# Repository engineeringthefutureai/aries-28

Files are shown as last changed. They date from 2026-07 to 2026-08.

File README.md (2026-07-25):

# Aries 28

**A tower-format mini private data center — a Raspberry Pi cluster that is a self-hosted private cloud, a k3s learning platform, and a documented hardware build, in one buildable box.**

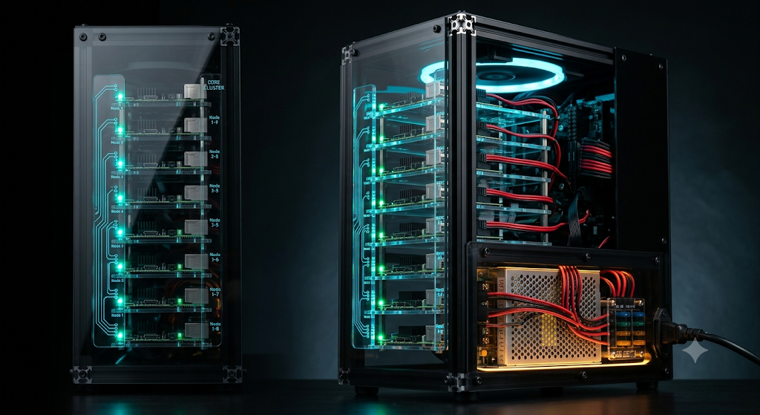
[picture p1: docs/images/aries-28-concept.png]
Aries 28 — concept render


> *Concept render (AI-generated) shown as the design target. To be replaced with a staged photograph of the real build.*

Aries 28 is an open hardware + software project: a **mini private data center** in a desktop tower — a cluster of Raspberry Pi boards running a real Kubernetes (k3s) cluster with distributed storage, housed in a laser-cut / 3D-printed / CNC enclosure. It has, in miniature, what a real data center has: redundant compute, a fused power-distribution system, managed cooling and airflow, structured network cabling, and a facilities layer (gateway, monitoring, orderly power sequencing). It is designed to be **replicated, understood, and modified** — every mechanical part, wiring decision, and cluster-setup step is documented, and the fabrication files are first-class artifacts alongside the code. An optional lighting layer is included for those who want it, but the enclosure and its illumination are presentation, not requirements.

It is deliberately *not* a performance machine. It is a machine for **learning** — Kubernetes control-plane redundancy, distributed storage, networking, power distribution, and physical fabrication — and a documented, hand-built piece of hardware. It provides node-level fault tolerance within the cluster; it is a single tower with acknowledged single points of failure (see the design doc), not a highly-available production system.

> **Status:** Active build. Documentation and design files are ahead of the physical build in places — treat this as a living project, not a finished kit.

---

## What it is

- **A mini data center:** redundant compute, fused power distribution, managed cooling, and structured cabling — the concerns of a real facility, at hobby scale, which is much of what makes it educational.
- **A cluster:** one or more single-board computers running k3s (lightweight Kubernetes) — starting from a single working node and scaling out with no fixed limit as boards are added. Added nodes become workers that expand the cluster's compute capacity; control-plane redundancy (HA with embedded etcd) is available along the way, but the cluster's growth is about overall capacity, not a fixed topology.
- **A private cloud:** distributed block storage and self-hosted apps, with an offline-capable design (self-hosted container registry, no external dependencies after setup).
- **An enclosure (optional aesthetic):** a black anodized 2020 aluminum-extrusion frame with acrylic panels, an exposed and serviceable power bay, and an optional lighting layer — including a status-lighting system that can reflect live cluster state. The styling is one implementation's choice, not a requirement.
- **A curriculum:** the build teaches control-plane quorum, distributed storage, routing/VLANs, infrastructure-as-code, power/fusing, and mechanical design — each embedded in a working part of the machine.

## What makes it different

Most Pi-cluster projects publish either the software (k3s scripts) *or* a case STL. Aries 28 aims to publish the **complete package**: mechanical design (STL / SVG / CAD), power and electrical design, cluster setup runbooks, and the reasoning behind each decision — so someone can replicate the whole thing or fork any layer of it.

The enclosure treats things other builds hide as **features**: the power supply and its wiring are on display behind smoked acrylic, dressed like the machine's power core; the boards ride on carriers that show through the panels; and the lighting does double duty as ambient mood and live status readout.

---

## Philosophy — earn the right to scale

Aries 28 is built on one principle: **earn the right to scale.** Complexity is added only once the simpler version works and its limits are understood — never preemptively.

**Start with one node.** The cluster begins as a single board on the workbench and is a *complete, working cluster at that stage* — it schedules workloads and serves traffic with one node. There is no "not yet functional" phase waiting on the rest of the hardware. From there it grows: a second node, then a high-availability control plane, then storage replication, then the physical enclosure — each step added because the previous one was proven and its constraints were felt firsthand. You don't build a distributed system to learn distribution; you build the smallest working thing and let its failures teach you what the next piece is for.

**The physical form earns its complexity the same way.** Boards run on the bench before they get a frame. The frame is proven square before panels go on. Lighting starts as a single power feed before it becomes a status system. Nothing is fabricated in final form until the design behind it has been tested — cardboard and cheap prints before acrylic and PETG.

**Neatness is engineering, not decoration.** A wire mess teaches nothing and hides its own faults; neatly organized, labeled, serviceable cabling is the foundation of a system you can actually grow and maintain. The same is true of the code and the documentation. The effort spent making the build *legible* — dressed cables, standardized interfaces, documented decisions — is not vanity; it is what makes the next change possible without a rebuild. A project you can't service is a project you can't scale.

**Aesthetics, practicality, and education reinforce each other rather than competing.** The tower is intended to be presentable, useful as a private cloud, and instructive to build. The exposed, dressed power bay is presentable because it is well-organized; the standardized carriers look deliberate because they make the machine serviceable; the optional status lighting is decorative and also conveys real cluster state. Well-organized engineering, shown honestly, is the source of the appearance.

The result is a machine that is never "half-built" — it works at every stage, looks deliberate at every stage, and teaches something at every stage. It just gets bigger, and better-dressed, as it earns it.

---

## Repository layout

```
aries-28/
├── docs/                    # design documents & runbooks
│   ├── architecture.md          # START HERE — the containment hierarchy & design spine
│   ├── design-doc.md            # master design: physical, power, BOM, build phases, SPOFs
│   ├── network-design.md        # topology, gateway, VLANs, switching, load balancing, I/O
│   ├── dns-and-exposure.md      # naming, DNS, ingress, service exposure, TLS
│   ├── rack-design.md           # rack & board-mounting mechanism
│   ├── lighting-design.md       # optional two-tier lighting system
│   ├── node-setup.md            # k3s + partitioned-storage node runbook
│   ├── images/                  # renders and (later) build-log photos
│   └── diagrams/                # architecture diagram (Graphviz source + render)
├── hardware/                # fabrication files, grouped BY PART (not by format)
│   ├── README.md                # parts index + fabrication legend (methods/materials)
│   └── <part>/                  # each part: its own README + all format options
├── kubernetes/              # cluster manifests (generic example included)
├── ansible/                 # node provisioning (infrastructure-as-code) — placeholder
├── LICENSE                  # dual: MIT (code) + CC-BY-SA 4.0 (hardware/docs)
└── .gitignore
```

**Start with [`docs/architecture.md`](docs/architecture.md)** — it describes the containment hierarchy (system → deck → rack → bay → carrier) and the stable-interface principle that the rest of the design refers back to.

**Hardware is organized by part, not by file format.** A single part (a board carrier, say) may have a `.svg` (sheet-cut), an `.stl` (3D print), and a source file side by side — these are *fabrication options*, not competing versions. Each part folder has a README explaining its purpose, the available routes, and any open decisions. See [`hardware/README.md`](hardware/README.md) for the parts index and the fabrication legend.

---

## Hardware overview

**Frame:** black anodized 2020 aluminum extrusion, compact mid-tower proportions. Corner hardware is bought (metal, for squareness); brackets, mounts, and carriers are fabricated.

**Fabrication is described by requirement, not by tool.** This project was built with a specific (limited) set of tools, but the repo documents what each part *needs* — material, dimensions, tolerances, hole positions — so you can make it with whatever you have: a CO2 or diode laser, a CNC router, or a hand saw and a drill following the drawing. The provided files (SVG/STL/STEP) are references; the **requirements** are the spec. Each part's README states its material and constraints and lists the methods that satisfy them.

Broad categories:
- **3D-printed parts (PETG)** — carriers, mounts, cable management, bezels, spacers. Small enough to print; PETG preferred over PLA for heat tolerance (near the PSU) and toughness (flexing latches) — each part README explains where the choice matters.
- **Sheet parts (acrylic)** — panels and optionally carriers. Flat stock cut to outer dimensions with holes/cutouts at specified coordinates. Achievable by CO2 laser, CNC router, or careful hand-cutting (table/circular saw) plus a drill press — the drawing gives the dimensions; the method is yours. Large panels **cannot** be 3D-printed (size), so they are always sheet stock.
- **Bought parts** — extrusion, corner brackets, rods, PSU, switch, fans: precision/strength items where off-the-shelf beats fabrication.

Some parts have **multiple valid routes** — e.g. a carrier can be 3D-printed in PETG *or* cut from acrylic (any color) on a laser/CNC with separate spacers. Clear or translucent acrylic gives more light transmission and edge-lit highlights; opaque/black gives contrast and hides what's behind it — the choice is aesthetic and depends on tool access and available materials. These are options, not a ranking; pick per your tools, materials, and preference.

**Boards — a deliberately heterogeneous fleet.** Different single-board-computer (SBC) generations and models play different roles, and their physical differences shape the wiring and mechanical design. This build uses Raspberry Pi boards, but the design is **not Pi-specific** — the standardized carrier/rack interface is meant to accommodate other SBCs too (Orange Pi and similar, or future SoC / compute modules), and even boards with different footprints. Larger boards (e.g. an Arduino Uno Q or an oversized SBC) may require a carrier variant or a bay-pitch adjustment, but the rack architecture is designed to absorb that rather than be rebuilt for it.

The Raspberry Pi fleet used here:

| Board | Role in cluster | Notable traits that affect the build |
|---|---|---|
| **Raspberry Pi 5** | control-plane / storage nodes | Has a built-in power button header (J2) — but its location on the board makes wiring a front-panel service button awkward; placement is an open design question. Fastest board; NVMe via PCIe HAT for storage. Ethernet port position differs from the Pi 4 (see cabling note below). |
| **Raspberry Pi 4** | gateway / worker nodes | **No built-in power-button header** — graceful shutdown for servicing needs an alternative (a GPIO-driven soft-power via `gpio-shutdown` overlay, or a wired button to the right pins). Ethernet port is on the **opposite side** vs. the Pi 5 (see cabling note below). |
| **Raspberry Pi 3A+** | LED / display driver ("face" node), outside the cluster | **No built-in Ethernet** — a USB-to-Ethernet adapter is used to keep it off Wi-Fi (the internal network is wired-only by design). Small footprint; drives the status LEDs and dashboard. |

**Board interchangeability & cabling.** Interchangeability is a **crucial design feature** — it's what makes future upgrades and expansion possible without rebuilding the machine. The carrier interface is standardized, and the carriers are shaped to **accommodate slightly different physical board shapes**, so a Pi 4, a Pi 5, or a different SBC entirely can occupy the same bay. Any node can be swapped for a newer or different board as generations improve, and empty bays can be populated later — the rack doesn't change. What differs between board types is mainly the **Ethernet jack position**, so the cabling is designed to absorb that: each node's Ethernet cable has **individually adjustable slack**, with the excess parked as a hidden service loop in the cable-management zone. Swapping one board type for another (jack a few cm over) is handled by adjusting that one cable's slack — no re-running cable, no harness rebuild, and other nodes' cabling is undisturbed.

**Cable management as a design element:** Ethernet runs are organized into neat parallel bundles using 3D-printed cable-holder braces. These do double duty — they hold the parallel runs so the wiring reads as deliberate (and photographs well through the panels), *and* they park each cable's adjustable service loop, so individual cables can be lengthened/shortened without touching the rest. Serviceability and aesthetics in one part.

**Power:** a single enclosed switching supply feeds a fused distribution bus; the power bay is vented and displayed as a feature. Mains safety (grounding, GFCI) is addressed in the design doc.

**Lighting:** two independent tiers — a non-addressable single-color ambient glow (no controller, powered straight from the fuse block) and a later addressable status system (reflects cluster state). See [`docs/lighting-design.md`](docs/lighting-design.md).

---

## Software overview

- **k3s** (lightweight Kubernetes) — starts as a single working node (a complete cluster on its own) and scales out with no fixed limit as nodes are added, expanding compute capacity. Control-plane redundancy (HA with embedded etcd) is available as the cluster grows.
- **Distributed storage** across nodes so a node loss doesn't lose data.
- **Offline-capable:** self-hosted container registry so the cluster can be rebuilt without internet access after initial setup.
- **Infrastructure-as-code:** node provisioning and cluster config are captured (Ansible + manifests), so nodes are reproducible rather than hand-configured.

Node bring-up — including partitioned NVMe (separate etcd and data), the Raspberry-Pi-specific kernel tweaks, and the k3s install — is documented step-by-step in [`docs/node-setup.md`](docs/node-setup.md).

---

## Lessons embedded in the build

Each is a working part of the machine, not a tutorial:

1. Kubernetes control-plane redundancy — etcd quorum, why 3 nodes (node-level fault tolerance, not system-wide HA)
2. Distributed storage and node-loss behavior
3. Routing / DHCP / DNS / VLANs (the gateway)
4. Infrastructure-as-code + GitOps
5. Power distribution, fusing, voltage-drop calibration
6. Node lifecycle: provision, drain, replace, recover
7. Scheduling on heterogeneous nodes (mixed RAM/roles)
8. Backup discipline
9. Power sequencing / orderly shutdown

---

## Status & roadmap

This is an in-progress build. Broad phases:

1. Bench cluster (prove software on loose boards)
2. Frame & power (fabricate, wire, calibrate)
3. Full integration (rack, panels, networking, control-plane quorum)
4. Cloud layer (storage, apps, registry)
5. Lighting & status system
6. Soft-power circuit

See `docs/design-doc.md` for the detailed phase breakdown.

---

## Reproducing it

You do **not** need to replicate the exact fleet. The design is intentionally modular:
- Board mix is flexible — the carrier/rack interface is standardized, so any Pi generation drops into any bay; cabling absorbs the differences via adjustable slack.
- Fabrication is tool-agnostic — parts are specified by requirement (material, dimensions, tolerances), so laser, CNC, or hand tools all work.
- Software runs on any modern Pi cluster; the runbooks are generic k3s.

Prices and part availability vary (this project was designed during a period of unusually high RAM/storage prices — see the BOM notes). Full from-scratch replication is roughly **$984–$1,164** (see `docs/design-doc.md` §7). Treat the BOM as a starting reference, not a fixed shopping list.

---

## License

Dual-licensed:
- **Code** (manifests, Ansible, scripts): MIT
- **Hardware & documentation** (STL, SVG, CAD, docs): CC-BY-SA 4.0

See [`LICENSE`](LICENSE). In short: use it, modify it, build your own — attribution appreciated, and share hardware/doc derivatives alike.

---

## Contributing

Issues, forks, and build-logs-of-your-own are welcome. If you build one, adapt a part for a different board, or improve a design, a PR or a link back is the best kind of feedback.

*Aries 28 — earn the right to scale.*

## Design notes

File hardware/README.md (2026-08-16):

# Hardware

Fabrication files for Aries 28, organized **by part**. Each part has its own folder containing a `README.md` and all of its file-format options side by side. A part may offer several fabrication routes (for example a 3D-printable `.stl` and a laser/CNC `.svg`); these are **options, not competing versions** — the part's README explains which route each file serves and what is decided or open.

## The rod-and-bead rack is generated

Plates, rods, bay bases, bay posts, the carrier, and the board they hold are built by a suite of Python scripts that run inside FreeCAD. The `.svg` and `.stl` files for those parts are **exports from that model**, not drawings maintained by hand: a change goes into the generator, and the cut files are re-exported. See [`MODEL.md`](MODEL.md) for how to run it, what each generator builds, and which gaps are known and still open.

Everything else here — panels, frame, power bay, and the rest — is still specified directly, as below.

## Fabrication is specified by requirement, not by tool

Files here are references. The **requirement** — material, dimensions, tolerances, hole positions — is the specification. Any process that meets it is valid: a CO2 or diode laser, a CNC router, or hand tools (saw and drill press) following the drawing. Where a dimensioned drawing is provided, it is the authority; the `.svg`/`.stl`/`.step` files are conveniences for specific routes.

For the generated parts this is unchanged in spirit but sharper in practice: the model carries the requirement, and its exports are one more convenience alongside the drawing. Where an export and the model disagree, the export is stale.

## Method legend

| Tag | Method | Typical use | Notes |
|---|---|---|---|
| `[PRINT]` | 3D print (FDM) | carriers, mounts, cable management, bezels, spacers | PETG preferred over PLA for heat tolerance and toughness; per-part README notes where this matters |
| `[SHEET]` | Laser / CNC / hand-cut sheet stock | panels, sheet carriers | Flat stock cut to outer dimensions with holes/cutouts at specified coordinates. Large panels cannot be printed (size) and are always sheet stock. Any color acrylic is acceptable; clear/translucent transmits more light, opaque gives contrast |
| `[BUY]` | Off-the-shelf | extrusion, corner brackets, rods, PSU, switch, fans, keystones | Precision or strength items where a commodity part is better than fabricating; prefer an existing standard where one exists |

## Material notes

- **PETG vs. PLA (printed parts):** PLA softens near ~50–60 °C and is brittle; PETG tolerates ~80 °C and flexes before failing. Use PETG for load-bearing parts, parts near the power supply, and any snap/latch feature. PLA is acceptable for test-fit mockups.
- **Acrylic (sheet parts):** any color; the choice is aesthetic and depends on tool access and available materials. Some cutting methods cannot cut some materials (e.g. certain lasers and clear acrylic) — this is a tool constraint, not a design one; follow the dimensions with whatever cuts the chosen stock.
- **The enclosure and any lighting are an optional presentation layer.** A functional cluster does not require the smoked panels, engraving, or LEDs.

## Parts index

| Part | Folder | Purpose | Routes | Status |
|---|---|---|---|---|
| Carrier | [`carrier/`](carrier/) | Holds one SBC; mounts into the rack | `[PRINT]` / `[SHEET]` | generated; SHEET exported (`carrier-rpi-b.svg`, spacers nested); PRINT STL pending |
| Spacer | [`spacer/`](spacer/) | Lifts a board off a sheet carrier | `[SHEET]` / `[PRINT]` | superseded for SHEET route — nested in the carrier SVG; see carrier |
| Rack | [`rack/`](rack/) | Cartridge of bays at one pitch (30 mm or 42 mm) | `[SHEET]` / `[PRINT]` / `[BUY]` | generated; plates exported, bay base and bay post designed and printable (`rack-bay-base.stl`, `rack-bay-post-30.stl`); cartridge not yet assembled |
| Panels | [`panels/`](panels/) | Enclosure walls (show/solid faces) | `[SHEET]` | pending; optional layer |
| Frame | [`frame/`](frame/) | 2020 extrusion skeleton + corners | `[BUY]` | specified (cut plan pending) |
| Power bay | [`power-bay/`](power-bay/) | PSU/fuse/distribution mounting | `[PRINT]` / `[BUY]` | pending |
| Switch mount | [`switch-mount/`](switch-mount/) | Cradle for up to 3 identical switches | `[PRINT]` | pending (no off-the-shelf standard → fabricated) |
| Cable brace | [`cable-brace/`](cable-brace/) | Parallel-run holder + service-loop park | `[PRINT]` | pending |
| Connection panel | [`connection-panel/`](connection-panel/) | External I/O face (inlet, soft-power toggle, Decora) | `[SHEET]` + `[BUY]` | specified (Decora + keystones) |

Statuses are indicative and will change as the build progresses. "Pending" means the requirement is described in the design docs but no fabrication file has been finalized. "Generated" means the part comes out of the model described in [`MODEL.md`](MODEL.md), and the files in its folder are exports from it.

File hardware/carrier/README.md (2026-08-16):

# Part: Carrier (board holder)

The carrier is the standardized tray that holds one single-board computer and mounts it into the rack. It is the core interchangeability element of the whole machine: **the rack interfaces only with the carrier, never with the board directly**, so any board — a Raspberry Pi 4, a Pi 5, or a different SBC entirely — can occupy any bay as long as it sits on a compatible carrier.

---

## Purpose & role

- Holds one SBC on standoffs/spacers, lifting it off the carrier for airflow and connector clearance.
- Presents a **single, standard mechanical interface to the rack** (the rod/bead engagement or slide, depending on rack variant) regardless of what board is on it.
- Carries per-node identification (engraved node name/number) and, in the styled build, decorative engraving that doubles as edge-lit lighting.
- Makes a node a **field-replaceable unit**: to service or swap a node, you handle its carrier, not loose boards and cables.

## Design status

- **Geometry / interface:** the rack-facing geometry is the fixed spec. Do not change it per board — that is what keeps bays interchangeable.
- **Board mounting pattern:** varies by board (hole spacing differs between SBCs). This is the *only* part of the carrier that changes between board types; the outer/rack interface stays constant.
- **Fabrication method:** intentionally left as an option — see below.

## Interchangeability

The carrier is what makes future upgrades and expansion possible without rebuilding the machine:

- **Same bay, any board.** Because the rack sees only the carrier, a newer or different board can replace an older one in the same bay. Empty bays can be populated later.
- **Accommodates slightly different board shapes.** The carrier is designed with enough margin to hold boards whose outlines differ modestly; substantially larger boards may need a carrier variant and possibly a bay-pitch adjustment (the rack architecture is designed to absorb this rather than require a rebuild).
- **Board-specific detail lives here, not in the rack.** Hole pattern and any board-specific clearance are properties of the carrier; the cabling absorbs connector-position differences separately (see the cable-management part).

---

## Fabrication — options, not a ranking

The carrier can be made by more than one method. Pick per your tools, materials, and preference; neither is "the final" version.

| Route | Process | Material | Notes |
|---|---|---|---|
| **Printed** | 3D print (FDM) | **PETG** | Integrates standoffs/bosses directly (no separate spacers). Tougher and more heat-tolerant than PLA — see material note. Best when you want an all-in-one part. STL pending (see below). |
| **Sheet-cut** | Laser (or CNC, or careful hand-cutting + drill) | **Acrylic**, any color, ~3 mm | Flat plate; the spacers needed for vertical isolation are **nested in the same laser file**, cut from the plate's own cutout waste rather than a separately-designed part — see `carrier-rpi-b.svg`. Clear/translucent acrylic transmits light for edge-lit effects; opaque gives contrast. |

**Requirement, not tool.** What the carrier needs is a flat, rigid plate of the specified outer geometry with the board's mounting holes at the correct coordinates and the rack-interface features accurate. Any process that achieves that — FDM printer, CO2 or diode laser, CNC router, or a saw and a drill press following the drawing — is valid. The provided `.svg` / `.stl` / `.step` files are references for those routes; the dimensioned drawing is the actual spec.

### Material note — PETG vs. PLA (printed route)

Use **PETG**, not PLA, for the printed carrier:
- **Heat:** PLA softens (~50–60 °C) and can creep under sustained load or warmth; carriers may sit near the power bay or in a warm environment. PETG tolerates ~80 °C.
- **Toughness:** PLA is brittle and can crack at thin sections or retention features; PETG flexes before failing, which matters for any snap/latch geometry and for a part that is handled during service.
- PLA is fine for **test-fit mockups** — print a cheap PLA carrier first to check board fit and rack engagement, then commit the real part in PETG.

### Material note — acrylic (sheet route)

- Any color works; the choice is aesthetic and depends on tool access and material on hand. Clear/translucent gives more light transmission and edge-lit highlights; opaque/black gives contrast and hides what is behind it.
- Sheet carriers need spacers to lift the board off the plate for vertical isolation; `carrier-rpi-b.svg` cuts these from the carrier's own cutout waste in the same laser pass — see the spacer part for the rationale, though the standalone spacer design there is superseded for this route.
- Some tools cannot cut some materials (e.g. certain lasers vs. clear acrylic); this is a *tool* constraint, not a design one. Follow the dimensions with whatever cuts your chosen stock.

---

## Files in this folder

*(Populated as the design is finalized — filenames indicative.)*

| File | Route | Purpose |
|---|---|---|
| `carrier-rpi-b.svg` | `[SHEET]` | Laser-cut carrier for the Pi 3B/4B/5 shared footprint. Its rod/pivot bores share rod-hole placement with [`../rack/rack-top-bottom.svg`](../rack/rack-top-bottom.svg); both come from the same function in the model, so they cannot drift apart. Nests the vertical-isolation spacers as cutouts within the same file — one laser pass produces the carrier plate and its spacers together, no separate spacer part to cut. |
| `carrier_plate_generator.py` | — | Generator for the carrier: hook on the left, fork on the right, spacer bosses for the board. |
| `pcb_generator.py` | — | The board and its port block — **the parameter source for the whole model**. Board size, hole spacing and hole diameter are set here and everything else follows. |
| `animate_carrier.FCMacro` | — | Swings one bay's carrier and board out of the rack, to check the mechanism. FreeCAD GUI only; `BAY` picks which bay. |

**`carrier-rpi-b.svg` is an export from the parametric model, not a drawing maintained here** — see [`../MODEL.md`](../MODEL.md). Change the generator and re-export; edits made directly to the SVG will be lost.

Printed (`[PRINT]`) route: STL pending. The model already builds the spacers as bosses integrated into the plate rather than separate pieces, which is what the printed part wants — the sheet route's nested cutouts are the adaptation, not the other way round.

The board's mounting pattern follows the Pi 3B/4B/5 footprint: M2.5 holes on 58 × 49mm, 3.5mm in from each edge of an 85 × 56mm board. Those are `pcb_generator.py`'s defaults; a different board is a different set of numbers there, not a different carrier design.

### Laser color convention (cut vs. engrave)

`carrier-rpi-b.svg` uses stroke **color** to separate the two operations it contains, since that's what both LightBurn and Creality Studio use to auto-split an imported SVG into independently-assignable layers — neither program reads a "cut this, engrave that" flag from the file itself:
- **Gray `#7F7F7F`, unfilled hairline** — outer profile, mounting holes, and the nested spacer cutouts. Assign this layer to **Cut**.
- **Blue `#0000FF`, unfilled** — the Aries glyph. Assign this layer to **Line/engrave the contour** (trace the outline, not a filled-region Scan/Fill). Unfilled on purpose — it's a contour engrave, not a solid-fill one.

Each program only auto-*groups* paths by color; you still assign Cut vs. Engrave to each color-layer once inside the software. In LightBurn that assignment persists across re-imports of an updated SVG as long as the colors stay consistent, so this is a one-time setup per color, not per re-export.

### Attribution — the Aries glyph

The glyph on the engrave layer is **not original to this project**:

> "Aries" by **Popsy**, from the [Popsy Hand Drawn Icons](https://popsy.gumroad.com/l/notion-icons-free) pack, via [SVG Repo](https://www.svgrepo.com/svg/474316/aries). Licensed **CC Attribution (CC BY)**.

That licence **requires** attribution wherever the artwork is used or redistributed, so the same credit is repeated as a comment inside `carrier-rpi-b.svg` itself — the file is often handed to a cutting service on its own, and the credit has to travel with it. Keep both if you re-export.

No CC version is stated by either source, so the credit is written unqualified; it satisfies the attribution condition of any CC BY version. Everything else in the file — the plate outline, mounting holes, rod bores, and nested spacers — is generated by this project and carries the repository's own licence.

The glyph is also planned as the front-panel brand mark (`docs/design-doc.md`). CC BY permits that, provided the attribution persists. Worth knowing that CC BY artwork can be used identically by anyone else, so if the mark is meant to be Aries 28's own identity it eventually wants an original drawing — a branding question, not a licensing one.

The file has repeatedly carried Shaper Origin–specific metadata (`xmlns:shaper` namespace, `shaper:cutType`/`cutOffset`/`toolDia` on every path) picked up from passing through that tool. It is stripped whenever it reappears — consistent with the project's "fabrication by requirement, not by tool" approach (`../README.md`) — so the file does not assume a specific machine. Worth checking after any round-trip through Shaper.

Note: these are current working files, not final released parts. The bay pitches are set at 30 mm (standard) / 42 mm (extended).

**The earlier fit test does not cover this file.** Three plywood carrier plates threaded onto the real 6.35mm rods alongside the plates, each carrying a Pi 5 — that passed, and validated the rod-hole interface *as it stood then*. The parametric model was not built to reproduce that geometry, and this SVG has since been re-exported from it, so the rod placement is no longer the placement that was tested. Carrier and plates still agree with each other by construction (both read `calculate_rod_centers()`), but the pair is unproven in plywood. A dimensioned reference drawing will be added as the design is finalized.

The bay parts now exist and print — a bay base plus four bay posts, see [`../rack/README.md`](../rack/README.md). Assembling carrier + plates + bay bases + bay posts + rods into one working cartridge, and confirming a carrier swings out of a populated rack, is the outstanding milestone.

Board variants are named by **hole-pattern group**, not by individual board, since the Pi 3B/4B/5 share one 85×56mm footprint and M2.5 holes on 58×49mm — one carrier fits all three (`design-doc.md` §3.2):
- `carrier-rpi-b.*` — Pi 3B / 4B / 5 (shared footprint)
- `carrier-rpi-a.*` — Pi 3A+ (65×56mm, same hole spacing, shorter)
- extensible: `carrier-<board>.*` for any additional board type whose hole pattern doesn't match an existing group

All variants share the same rack-facing interface; only the mounting-hole pattern changes between groups.

---

## Dependencies

- **Spacers** (sheet-cut route only) — lift the board off the plate for vertical isolation; nested directly in `carrier-rpi-b.svg` rather than a separate file. See the spacer part for the general rationale.
- **Rack** — defines the carrier's rack-interface geometry (rod/bead or slide). See the rack design doc.
- **Cable management** — connector-position differences between boards are absorbed by adjustable-slack cabling, not by the carrier. See the cable-management part.

## Related documentation

- `docs/rack-design.md` — the rack the carrier mounts into, and the mounting-mechanism options.
- `docs/design-doc.md` — overall physical design, bay pitch, board fleet, and where carriers sit in the build.

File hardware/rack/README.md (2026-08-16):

# Part: Rack

## Purpose & role
An independently-assemblable cartridge of bays at a single pitch, into which carriers mount. The rack is the unit of reconfiguration in the containment hierarchy (see `docs/architecture.md`): its internal pitch can change without affecting the deck it mounts into. Two pitch classes are planned — a dense compute rack and a taller expansion rack for nodes with vertical accessories (storage/AI HATs).

## Fabrication route(s)
Mixed by component: `[SHEET]` (top/bottom plates, laser-cut), `[PRINT]` (bases and posts, including the anchor and latch variants), `[BUY]` (stainless rods).

See the fabrication legend in [`../README.md`](../README.md) for method tags and material notes (PETG vs. PLA, acrylic, buy-vs-fabricate).

## Files in this folder
| File | Route | Purpose |
|---|---|---|
| `rack-top-bottom.svg` | `[SHEET]` | Laser-cut top and bottom plates for the rod-and-bead cartridge (`docs/rack-design.md` §4), with the rod holes that seat the four 6.35mm rods. |
| `rack-bay-base.stl` | `[PRINT]` | The bay base: four rod stations tied together by three webs, with the carrier riding in the 3mm band above them, and a cable comb on each of two sides — ethernet off the rear bridge, power on the left web. PETG. Pitch-independent — the same part serves the 30mm and 42mm racks. |
| `rack-bay-post-30.stl` | `[PRINT]` | The bay post: one of the collars that fill the rest of a 30mm bay, keyed into the base above so a stack cannot rotate out of register. PETG. **Three per bay** — front-left, front-right and rear-left. Named for the pitch it sets; the 42mm post is still to come. |
| `rack-bay-post-rr-30.stl` | `[PRINT]` | The rear-right post: the same part with one ethernet clip revolved onto its back, which faces 45° out of the rack's rear-right corner. PETG. One per bay. |
| `bay_base_generator.py`, `bay_post_generator.py` | — | Generators for the two parts above. |
| `rack_plate_generator.py`, `rods_generator.py` | — | Generators for the plates and the rods. |

**All three fabrication files above are exports from the parametric model, not drawings maintained here** — see [`../MODEL.md`](../MODEL.md) for how to run it and re-export. Change the generator, not the `.svg` or the `.stl`.

`rack-top-bottom.svg` is a single-color, cut-only file (no engrave layer, unlike the carrier). It carries no Shaper Origin metadata; it is a plain FreeCAD export whose stroke colour is set to the cut-layer convention described in [`../carrier/README.md`](../carrier/README.md).

## Status
In progress. The top/bottom plates moved from a printed STL to the laser-cut `rack-top-bottom.svg` above; the two bay pitches are set — 30 mm (dense/compute) and 42 mm (extended/expansion). The whole cartridge is now generated (see [`../MODEL.md`](../MODEL.md)), and the pitch is a single parameter: `Rack_Base.BayPitch`. See `docs/rack-design.md`.

**The bead is now two parts.** What used to be one four-tube bead per bay is a **bay base** plus four **bay posts** (three of one part and one of a rear-right variant that carries an ethernet clip). The base is only the bottom 6 mm — three webs, then a 3 mm band that matches the carrier's thickness — and the carrier rides in that band, resting on the webs and held down by the posts standing on it. Everything above is post. Three things fall out of the split: the base is the same part at every pitch, so only the post has to be reprinted for a 42 mm rack; each post's 225° opening faces the rack's diagonal, which hands the board back the 0.5 mm the old bead clipped off it; and the post being a plain collar retired the swept, flaring tube geometry that made the bead expensive to rebuild.

**A post stands on a landing pad.** A pad is a plain sector of the station's tube — bore, outer wall, two straight radial cuts, four rounded corners. It reaches as far round as the carrier lets it, which is measured rather than carved: cutting the pad to the carrier's actual silhouette gives a crescent tapering to knife points against the rod, with half its corners impossible to fillet. The pads are small on the front pair — a fifth of the annulus at the front-left, a third at the front-right — with the rest of each post's foot resting on the carrier plate itself. That is deliberate: it is what traps the carrier vertically, and a post carries only grams.

**The base carries both cable runs.** Two combs of eight clips each, one per bay so that the bottom bay's comb passes every bay's cable on the way up: ethernet off the back of the rear bridge, power on the left web. They are built on the same idea — a pocket tangent to the face it hangs off, so that face is the back wall, with a mouth narrower than the pocket so a cable is pressed in and stays — and differ in what they hold. The ethernet clip is a round bore for a jacketed patch lead; the power clip is a stadium two wire diameters deep, taking the node's bonded red/black pair **on edge**, red inboard. The ethernet comb stands the base's full 6 mm and needs a beam behind it because its upper half is in the band the carrier rides in; the power comb stays inside the 3 mm web, where the web is its backing and the carrier never meets it.

Both are overhung by the top and bottom plates, which are rectangles cut on the rod bounding box — by 0.675 mm at the rear, and completely on the left. That is a plate problem rather than a base one and the fix is cuts in `rack-top-bottom.svg`; see [`../MODEL.md`](../MODEL.md#known-gaps).

**Rod-hole placement is a shared interface — critical.** The rod holes in the plates and the carrier's rod/pivot bores must agree on rod spacing; a carrier that doesn't ride the same four rods as the plates it mounts between can't engage the rack. That agreement is now structural rather than a matter of care: both come from `calculate_rod_centers()` in the model, so the two cannot drift apart. Any change to rod placement is a change to that one function.

**The earlier fit test no longer certifies these files.** Plywood test-cuts of the *previous* SVG pair threaded cleanly onto the real 6.35mm rods, three carriers each holding a Pi 5 — that proved the rod-hole interface as it stood then. The model was not built to reproduce that geometry (its rod gap and front-left rod position both differ), and both files have since been re-exported from it. The interface is self-consistent, but the current geometry is unproven in plywood.

**Next milestone — assembly.** The bay base and bay post now exist and print: together they set the bay pitch, key into each other, and the base is relieved for the carrier's swing. What has not happened is putting plates + rods + bases + posts + carriers together into one working cartridge and confirming a carrier actually swings out of a populated rack. Known gaps that will bite there — the top plate's four blind key holes not yet being modelled, how much of each post's foot lands on the carrier rather than on its landing pad, and whether 45° of swing is enough to extract a carrier at all — are listed in [`../MODEL.md`](../MODEL.md#known-gaps).

**The top plate needs four holes that are not in the SVG.** The topmost bay's posts key into the top plate, and those holes are blind — a laser cuts through, and a through-hole would show on the rack's outside face — so they are drilled by hand after cutting. `rack-top-bottom.svg` is one file for both plates and deliberately does not carry them. See `docs/rack-design.md` §4.

## Dependencies
- Carrier — defines the rack-facing interface (rod/bead or slide); shares rod-hole placement with the top/bottom plates (see above).
- Deck — the rack mounts into the facilities/compute deck as a cartridge.

## Related documentation
- `docs/design-doc.md` — overall physical design and where this part fits.
- `docs/architecture.md` — the containment hierarchy and stable-interface rule.

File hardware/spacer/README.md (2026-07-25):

# Part: Spacer

## Purpose & role
Lifts a single-board computer off a flat sheet carrier, providing airflow beneath the board and clearance for bottom-side components and connectors. Required only for the sheet-cut carrier route; the printed carrier integrates equivalent standoff bosses and needs no separate spacer.

## Fabrication route(s)
`[SHEET]` (cut from the same stock as the carrier) or `[PRINT]`.

See the fabrication legend in [`../README.md`](../README.md) for method tags and material notes (PETG vs. PLA, acrylic, buy-vs-fabricate).

## Status
Superseded for the sheet-cut route: `hardware/carrier/carrier-rpi-b.svg` nests the spacers as cutouts within the carrier's own laser file, cut from the plate's waste material in the same pass — no standalone spacer file needed there. This part folder remains relevant only if a future printed-route spacer, or a spacer for a board/carrier combination not covered by that nested design, is ever needed as a separate piece.

## Dependencies
- Carrier (sheet route) — the spacer sits between board and carrier.
- Board mounting-hole pattern — determines spacer hole positions.

## Related documentation
- `docs/design-doc.md` — overall physical design and where this part fits.
- `docs/architecture.md` — the containment hierarchy and stable-interface rule.

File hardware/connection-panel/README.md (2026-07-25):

# Part: Connection panel

## Purpose & role
The single external-facing I/O face. Fixed cuts: IEC C14 power inlet (with switch/fuse), a recessed soft-power toggle (the DPST toggle from `docs/design-doc.md` §4.4 — a maintained-position switch, not a momentary button), and one standard Decora opening. Comms use off-the-shelf Decora + keystone inserts (RJ45 for WAN and MAINT, optional USB console, blanks) rather than custom-printed sub-panels — an existing modular standard is preferred where one exists. Only the acrylic cutout is fabricated.

## Fabrication route(s)
`[SHEET]` (acrylic cutout to the standard Decora opening dimensions) + `[BUY]` (Decora frame, keystones, IEC inlet, toggle).

See the fabrication legend in [`../README.md`](../README.md) for method tags and material notes (PETG vs. PLA, acrylic, buy-vs-fabricate).

## Status
Specified. See `docs/network-design.md` §8 and `docs/dns-and-exposure.md`.

## Dependencies
- Frame — the panel occupies a rear face opening.
- Network design — WAN/MAINT keystone assignment.

## Related documentation
- `docs/design-doc.md` — overall physical design and where this part fits.
- `docs/architecture.md` — the containment hierarchy and stable-interface rule.

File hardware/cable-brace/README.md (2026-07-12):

# Part: Cable brace

## Purpose & role
Holds Ethernet runs in tidy parallel bundles and parks each cable's individually-adjustable service loop. The service-loop function is what lets a board type be swapped (its jack position differs) by adjusting one cable's slack rather than re-running cable — supporting node interchangeability without a harness rebuild.

## Fabrication route(s)
`[PRINT]`.

See the fabrication legend in [`../README.md`](../README.md) for method tags and material notes (PETG vs. PLA, acrylic, buy-vs-fabricate).

## Status
Pending. Geometry follows the cable count and routing path.

## Dependencies
- Rack / frame — braces route cables along the structure.
- Interchangeability requirement — see README and design doc.

## Related documentation
- `docs/design-doc.md` — overall physical design and where this part fits.
- `docs/architecture.md` — the containment hierarchy and stable-interface rule.

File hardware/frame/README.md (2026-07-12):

# Part: Frame

## Purpose & role
The structural skeleton: black anodized 2020 aluminum extrusion in a compact tower form. Corner hardware is bought (metal, for squareness); everything mounted to the frame is fabricated or bought separately.

## Fabrication route(s)
`[BUY]` — extrusion cut to length, metal corner brackets/connectors, M5 T-nuts and screws. Frame squareness depends on accurate cuts (miter saw with a non-ferrous blade) plus metal corners.

See the fabrication legend in [`../README.md`](../README.md) for method tags and material notes (PETG vs. PLA, acrylic, buy-vs-fabricate).

## Status
Specified; cut plan (segment lengths) pending finalized internal dimensions.

## Dependencies
- All mounted parts reference the frame as datum.
- Panels, racks, and decks are sized to the assembled frame.

## Related documentation
- `docs/design-doc.md` — overall physical design and where this part fits.
- `docs/architecture.md` — the containment hierarchy and stable-interface rule.

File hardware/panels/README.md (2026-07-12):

# Part: Panels

## Purpose & role
The enclosure walls. Optional presentation layer — a functional cluster does not require them. Show faces (front, access side, power-bay side) may use smoked or clear acrylic; solid faces (back, bottom) use opaque stock. Panels surface-mount to the frame with printed clips rather than sliding into the extrusion slot (see design doc §3.3).

## Fabrication route(s)
`[SHEET]` — cut to outer dimensions with openings at specified coordinates. Large panels cannot be printed and are always sheet stock.

See the fabrication legend in [`../README.md`](../README.md) for method tags and material notes (PETG vs. PLA, acrylic, buy-vs-fabricate).

## Status
Pending. Per-panel dimensions follow the finalized frame size. Front panel carries optional engraving.

## Dependencies
- Frame — panels are sized to the assembled frame.
- Connection panel — the rear panel integrates the I/O face (separate part).
- Panel retainer clips (`[PRINT]`) — hold panels to the frame.

## Related documentation
- `docs/design-doc.md` — overall physical design and where this part fits.
- `docs/architecture.md` — the containment hierarchy and stable-interface rule.

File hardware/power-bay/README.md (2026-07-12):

# Part: Power bay

## Purpose & role
Mounting and organization for the power supply, fuse/distribution block, and dressed wiring on the facilities deck. Positioned low for stability and, in the styled build, displayed through a smoked side panel. Requires a PSU air gap and venting (see design doc thermal notes).

## Fabrication route(s)
`[PRINT]` mounts/combs + `[BUY]` (PSU, fuse block, connectors).

See the fabrication legend in [`../README.md`](../README.md) for method tags and material notes (PETG vs. PLA, acrylic, buy-vs-fabricate).

## Status
Pending. Layout follows the chosen PSU and fuse-block dimensions.

## Dependencies
- Frame — the bay occupies the lower deck footprint.
- Wiring/fusing — see design doc §4.

## Related documentation
- `docs/design-doc.md` — overall physical design and where this part fits.
- `docs/architecture.md` — the containment hierarchy and stable-interface rule.

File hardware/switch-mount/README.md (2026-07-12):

# Part: Switch mount

## Purpose & role
A cradle holding up to three identical 8-port switches in a switch rack on the facilities deck. Because these switches have no off-the-shelf mounting standard, this cradle is fabricated — an example of the 'fabricate only what has no existing standard' principle (contrast the connection panel, which uses off-the-shelf Decora).

## Fabrication route(s)
`[PRINT]` — sized to the specific switch model.

See the fabrication legend in [`../README.md`](../README.md) for method tags and material notes (PETG vs. PLA, acrylic, buy-vs-fabricate).

## Status
Pending. Dimensions follow the chosen switch (TP-Link TL-SG108E in the reference build).

## Dependencies
- Frame / facilities deck — the switch rack mounts low.
- Network design — cascade wiring, see `docs/network-design.md` §5.

## Related documentation
- `docs/design-doc.md` — overall physical design and where this part fits.
- `docs/architecture.md` — the containment hierarchy and stable-interface rule.

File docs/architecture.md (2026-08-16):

# Aries 28 — Physical Architecture: Hierarchical Reconfigurability

**The organizing principle of the entire physical design. Every mechanical decision refers back to this.**
Version 1.0 — July 2026

---

## 1. The idea

Aries 28 is decomposed into a strict containment hierarchy, where **each level absorbs a class of change so that change does not propagate upward.** The blast radius of any modification is bounded to exactly one unit at one level. This is the same principle as good software modularity — encapsulation behind stable interfaces — expressed in aluminum and acrylic.

The goal is a machine that never needs to be *rebuilt*, only *reconfigured locally* — and where the effort of any given change is proportional to how deep in the hierarchy it reaches. Routine changes touch the bottom of the hierarchy and are trivial; only radical, unforeseeable changes reach the top, and the design is built so that they almost never need to.

---

## 2. The hierarchy

| Level | Unit | Contains | What it is | Stable interface it presents upward |
|---|---|---|---|---|
| 0 | **System** | decks | The whole box: frame, panels, all contents | Its footprint / place on the shelf |
| 1 | **Deck** | racks *or* facilities gear | A horizontal sub-box within the system (e.g. facilities deck, compute deck) | A standard footprint mounting to the system frame |
| 2 | **Rack** | bays | An independently-assemblable cartridge of bays at one pitch | A standard cartridge mount to its deck |
| 3 | **Bay** | one carrier | A single slot at a defined pitch within a rack | A standard carrier interface (rod/bead or slide) |
| 4 | **Carrier** | one board | The tray holding one single-board computer | A standard mechanical face to the bay |
| (5) | **Board** | — | The compute unit itself | Its mounting-hole pattern + connectors |

Real data centers use the same shape: room → row → rack → shelf/U → server. Aries 28 is that logic scaled to a desktop: **system → deck → rack → bay → carrier → board.**

---

## 3. Bounded reconfiguration — change stops at its level

Each level is the unit of a particular kind of change. A change enters at the lowest level that can contain it and does not disturb anything above.

| Change | Enters at | Blast radius | Cost | Frequency |
|---|---|---|---|---|
| Reflash / replace a node with the same board type | **Carrier / Bay** | one node | trivial | routine |
| Swap a board for a different type that fits the pitch | **Bay** | one node (+ a carrier variant) | trivial | occasional |
| New board class needs a different pitch/size | **Rack** | one rack (reprint its posts or rebuild the cartridge; remount affected nodes) | moderate | rare |
| Add capacity of an existing class | **Rack** | add a rack cartridge, or populate empty bays | low–moderate | as needed |
| Facilities change (second switch, gateway/registry node, PSU) | **Deck** | one deck | moderate | rare |
| Fundamental redesign | **System** | the machine | rebuild | designed to be unnecessary |

**The load-bearing example — unforeseeable future hardware:** some future single-board computer beats the current fleet but is physically larger. This does *not* require rebuilding the tower. It enters at the **rack** level: add a new rack cartridge sized for it, or reconfigure an underutilized existing rack to the new pitch and remount both new and old nodes onto carriers for that rack. This is more work than a node swap, but *bounded* work: the remaining racks and the entire facilities deck are untouched and continue running. The future board cannot be predicted, but the change can be guaranteed to stay local.

---

## 4. Stable interfaces — the rule that makes it work

Bounded reconfiguration only holds if **each level presents a stable interface to the level above, independent of its own internals.** This is the encapsulation rule, and it is the single most important constraint in the physical design:

- A **carrier** presents a standard face to the bay — so the board on it can be anything (different SBC, different generation, different hole pattern) without the bay caring.
- A **bay** presents a standard carrier interface — so what a carrier holds is irrelevant to the rack.
- A **rack** presents a standard cartridge mount to its deck — so a rack's internal pitch/size can change without the deck caring.
- A **deck** presents a standard footprint to the system frame — so a deck's contents (compute vs. facilities) are irrelevant to the box.

As long as each interface is held constant, the internals of any level are free to change. Breaking an interface — making the rack mount depend on bay pitch, or the bay depend on board type — causes change to leak across boundaries, which returns the system to requiring a full rebuild for any modification. Every part should be designed to keep its upward interface constant.

---

## 5. The deck layer (current plan)

The system is split vertically into decks. Heavy, static infrastructure low; reconfigurable compute above.

- **Facilities deck (bottom, full footprint):** PSU, fuse block / distribution, network switch(es) — one now, a second cascaded later — and room for optional additional facilities nodes (gateway, self-hosted registry). This is the "power + network core," analogous to a data center's power and top-of-rack networking. Kept low for stability and serviceability; displayed as a feature through the panels.
- **Compute deck(s) (above):** one or more rack cartridges.

## 6. The rack layer (current plan)

Racks are independent cartridges, each at a single bay pitch, sized to a **class** of node. Interchangeability is guaranteed *within* a class, not forced *across* classes — which is what lets different node shapes coexist without a single compromise pitch.

- **Compute rack — dense pitch (30 mm):** bare/diskless nodes (compute + network only) — the gateway, light worker, and face node. Tight because there is nothing stacked to heat-soak; the small gap is adequate airflow for a cooled bare board.
- **Expansion rack — tall pitch (42 mm):** nodes with vertical accessories — NVMe HATs (etcd on every control-plane node, plus the storage node), AI accelerators, or future add-ons. Now most of the compute fleet, not a minority case, since SD isn't recommended for etcd (design-doc.md §4.3). Generous height each (which also means generous airflow). Sized from the current ~34 mm Pi-5-plus-SSD stack plus headroom for taller HATs and future options.

Two pitches means two post lengths (rod-and-bead rack; the bridged base is the same at both) — a one-time design cost, not a per-change one. Each rack remains an independently-assemblable cartridge: build and wire it on the bench, drop it into its deck as a unit, and reconfigure it later without disturbing its neighbors.

## 7. The bay & carrier layers

Covered in detail in the rack design doc and the carrier part README. In short:
- A **bay** is one pitch-slot presenting the standard carrier interface.
- A **carrier** is the standardized tray that makes a node a field-replaceable unit and holds the board-specific detail (hole pattern), so the board type never propagates up to the bay.

---

## 8. Why this matters (and why it's worth the extra fabrication)

Uniform-everything would be simpler to build but would either waste space (one tall pitch for all) or force compromises (one medium pitch that serves nothing well). Fully bespoke would pack tightest but make every change a rebuild. Hierarchical reconfigurability is the middle path that real infrastructure converges on: **standardize interfaces, vary internals, bound every change to one level.**

The cost is a modest, one-time design variety (two rack pitches, a few carrier variants). The benefit is durable: the machine grows, upgrades, and adapts to hardware that does not yet exist, and every such change is a bounded, local operation rather than a teardown. It functions at every stage and continues to function as it changes.

*This is the conceptual spine of the build. When in doubt about a physical decision, ask: which level does this belong to, and does it keep that level's upward interface constant?*

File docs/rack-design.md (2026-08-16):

# Aries 28 — Rack & Mounting System Design

**Companion to the main design doc. Scope: node bays, rack structure, board retention, cable management, LED integration.**
Version 0.5 — August 2026 · Status: Concept C (rod-and-bead) is lead candidate; the cartridge is now a parametric model (`hardware/MODEL.md`) and the standard bay parts are designed and printable; full cartridge assembly still pending
Changelog: v0.5 — the bead split into a pitch-independent **bay base** plus four identical 225° **bay posts** per bay (§4); the posts' diagonal openings retire the 0.5 mm board clip, and the base is now the only part carrying geometry. The base also grew both **cable combs** — ethernet off the rear bridge, power on the left web (§4, §8). v0.4 — rack moved from drawn files to a generated model; standard 30mm bead designed, printed-form STL committed; plates and carrier re-exported from the model, which means the v0.3 fit test no longer covers the current geometry (see §6 item 3). v0.3 — initial fit test passed (carrier + top/bottom plates on real 6.35mm rods, plywood test-cut, three Pi 5s mounted); confirms §4's rod-bore-fit risk (item 3) for the plate/carrier side, bead side still open. v0.2 — added Concept C rod-and-bead swing rack (lead), demoted pillars to fallback, updated decision + open questions. v0.1 — concepts A/B, materials, detent ladder, buttons.

---

## 1. Requirements

| # | Requirement | Source |
|---|---|---|
| R1 | Tool-free insert/remove of any node (power unplugged first — cold-swap mechanically, drain-first at cluster level) | live-surgery goal |
| R2 | Every connector that gets pushed/pulled (ethernet, XT30, SD) sits adjacent to a supported mount point | PCB flex rule |
| R3 | Any NVMe-equipped node (Pi 5 + X1001, 3-hole HAT) — every control-plane node plus the storage node — mounts in the same system, in an extended-pitch (42 mm) bay | main doc §3.1, §4.3 |
| R4 | Retention mechanism is a replaceable wear part — worn parts swap without rebuilding the rack | 50-cycle problem |
| R5 | Boards visible as display objects; mounting hardware minimal or concealed | aesthetics (optional) |
| R6 | Cable routing is designed, not incidental — for serviceability and strain management | serviceability |
| R7 | v1 optimizes for simple manufacturing; iteration expected | process |
| R8 | Unused mounting provisions left throughout for unforeseen additions | pegboard's 10% |
| R9 | Rack height not limited by printer build volume | rod-and-bead insight |

---

## 2. Concept A — Direct board mount (ball-detent pillars) — shelved

Boards snap by their own mounting holes onto spring-ball pillar clips. Maximum floating-silicon look, fewest parts — but insertion force and wear land on the PCB (violates R4), the X1001 stack occupies the holes (breaks R3), and connector push demands all four corners engaged. Kept as a bench experiment only: one 4-point set for a spare Pi 4, cycle-tested for hole wear.

## 3. Concept B — Carrier + fixed pillars (fallback)

Per-board carrier plate (board bolted conventionally); carrier hook-and-rotates onto fixed printed pillars, ball detents retain. Solves R2/R3/R4. Remains the fallback if Concept C's geometry tests fail. Carrier design, materials, and detents from this concept carry forward into C unchanged.

## 4. Concept C — Rod-and-bead swing rack (LEAD)

Four vertical **1/4" (6.35mm) smooth stainless rods** between top and bottom plates; printed spacers threaded onto the rods like an abacus set the bay pitch. One spacer was originally one four-tube **bead** per bay, which is where the concept gets its name; as of v0.5 it is a bridged **bay base** plus four **bay posts** (below). The whole cartridge is sandwiched plate-to-plate and bolted into the 2020 frame. Rack height is set by rod length, not printer volume (R9).

**Corner role assignment (each rod has a job):**

| Corner | Role | Carrier feature |
|---|---|---|
| Front-left | **Pivot** — carrier swings out like a gate | closed ring / deep-C bore riding the rod (dry PTFE lube = entire bearing budget) |
| Rear-right | **Latch** — passive notch on the carrier; the rack side carries the active spring finger + pull tab (see §7). Release = right hand pulls tab, left hand rotates. Zero pull force on the board — deliberate two-handed removal by construction. | plain open U-notch + small rectangular engagement notch on the edge |
| Rear-left | bridged support | open C-notch (departs sideways during swing) |
| Front-right | independent stack, open side | open C-notch (exit side) |

**All four stacks are bridged** — a base is one four-station part. Bridges run up the left side (front-left to rear-left), across the rear, and up the right (front-right to rear-right). They occupy only the bottom 3 mm, below the height the carrier rides at, so the front-right face stays open. Unlatch rear-right → carrier swings out the front-right opening → board inspectable **with cables still attached**. This is the property no slide-in shelf has.

*Changed in v0.4.* Earlier revisions left the front-right stack independent, on the assumption that bridging it would close the exit. Bridging below carrier height does not, and one four-tube part is easier to print, handle, and key than three plus a loose stack.

*Changed in v0.5.* **The bead is two parts: a bay base and four bay posts.** The base is the bottom 6 mm of a bay — the three bridges, then a 3 mm band matching the carrier's thickness. The carrier rides in that band, resting on the bridges and captured from above by the posts standing around it. Everything above is a plain 225° collar per rod, four identical ones per bay. What the split buys:
- **The base is pitch-independent.** Only the post changes length between the 30 mm and 42 mm racks, so one base part serves both.
- **The board gets its clearance back.** Each post turns its opening onto the rack's diagonal, so the wall wraps the outside of the stack; where the old full tube overhung the board by 0.5 mm, the nearest post wall now stands 1.0 mm off it.
- **A post clips on rather than threading.** 225° is over half the rod.
- **The geometry got cheap.** The bead's swept, flaring tubes — trimmed to a wedge at carrier height and lofted open above it — are gone; a post is a sector, a bore, four fillets and a stub.

A post stands on a **landing pad** — a plain sector of that station's tube in the 3 mm band, cut back with two straight radial lines to wherever the carrier lets it reach, with all four corners rounded (1.0 mm outer, 0.5 mm bore). How far it reaches is measured off the carrier rather than carved from it; the pivot gives up the swing angle as well, off the leading end. On the front pair the pad is only a fifth to a third of the annulus, and the rest of the foot rests on the carrier plate itself, which is what traps the carrier vertically. Small pads are acceptable here — a post carries grams, not the rack.

**Bay base and bay post system:**
- Standard (compute) post: sets the **30 mm** compute pitch together with the base, keyed to its neighbours so the whole stack inherits one orientation (round rods can't key themselves).
  - *Built* (`hardware/rack/rack-bay-base.stl` + `hardware/rack/rack-bay-post-30.stl`, generated by `bay_base_generator.py` and `bay_post_generator.py`). Keying is a round stub on top of each post dropping into a matching hole in the base above — 2.4 × 1 mm, standing proud of the pitch so stacking height is unaffected by it.
  - **Orientation is taken at the top, not the bottom.** The top plate receives the topmost bay's four stubs in **blind** holes; keying then propagates down the stack, so the base plate needs nothing. Blind because a through-hole would show on the outside face of the rack — which also means they are **drilled by hand, not cut**: a laser only makes through-holes. Four holes, top plate only, so they stay out of `rack-top-bottom.svg` (one file serves both plates). Not yet in the model.
- **The rear-right post carries the ethernet drop.** Three posts in a bay are the plain collar; the fourth has one C-clip on its back, which faces 45° out of the rack's rear-right corner — where the run leaves the base's comb and turns toward the node. The clip is **revolved about the post's axis** rather than stuck onto it, 15° either side of the back, so it follows the collar as a saddle; its profile is a bore circle and an outer circle with the two ends of the C rounded off, so there is no corner on it anywhere. 7/32 in bore tangent to the post's shell (which makes the collar the back of the clip and the rest it sits on), 5/32 in mouth opening radially outward, sitting on the post's own bottom face so it picks the cable up where the base below hands it over. Nothing is cut from the post. Built (`hardware/rack/rack-bay-post-rr-30.stl`).
- **Anchor bases:** special bases with tabs/T-nut bosses bolting the cartridge to the 2020 frame at mid-heights — attachment and rod anti-bowing brace in one part.
- **Cable combs: built, and part of the standard base.** Two of them, one per run, both eight clips because the bottom bay's comb passes every bay's cable on the way up.
  - **Ethernet, off the back of the rear bridge.** Bore 7/32 in on a 5/32 in mouth so a cable is pressed in and stays, 1/8 in of material between clips, 6 mm proud, offset 15.15 mm from the base's right edge. Each bore is tangent to the back of the bridge, so the bridge is the back wall of every clip and the comb stays shallow. It stands the full 6 mm thickness of the base rather than the bridge's 3 mm, backed by a beam running rod-centre to rod-centre forward to the line tangent to both rear rod bores — which clears the carrier by one rod radius at its deepest, swallows both rear landing pads, and turns the back of the base into a full-height beam rather than a 3 mm web.
  - **Power, on the left web.** The XT30 pigtail's red and black leads are 3/32 in each and bonded, so the clip is not a bore but a stadium two wire diameters long and one wide, standing normal to the web: the pair drops in **on edge**, red inboard against the web and black outboard behind it. Mouth 90% of the wire, 1/8 in between clips, 6 mm proud, centred on the web. No backing and no beam — it stays inside the 3 mm web band, where the web is directly behind every clip, so it costs the carrier nothing.

  See §8 for how the runs use them.
- Other special parts as needed: LED-strip and button-mount variants (R8 lives here — the bay is the expansion slot). A post is a good host for the per-rod ones, since it is small and there are four per bay.
- Extended post: sets the **42 mm** extended pitch for the tall rack — nodes with a vertical HAT, such as a Pi 5 + NVMe stack (etcd on a control-plane node, or bulk storage — R3). Two pitches → two post lengths and one base; each rack cartridge uses one length throughout (architecture.md §6).

**Tolerance & preload (the failure mode to engineer against):** all-smooth rods mean pitch is set purely by the stack — printed height error accumulates, and there are now two parts per bay contributing it rather than one. Countermeasures: print each rod's parts in one batch (same profile, same squish); design the **topmost post as compliant** (printed wave-spring profile, or an O-ring under the top plate) so plate clamping preloads the stack solid regardless of ±0.5mm accumulated error; carriers get ±1mm vertical compliance at the latch.

**Rod ends:** blind pockets in top/bottom plates; frame bolts provide clamping force. No threads, no e-clips in v1. Top/bottom plates are laser-cut sheet (`hardware/rack/rack-top-bottom.svg`) rather than printed; their rod-hole placement is shared with the carrier's rod/pivot bores (`hardware/carrier/carrier-rpi-b.svg`). That sharing is now structural: both come from one function in the model (`hardware/MODEL.md`), so the two cannot drift apart.

**Assembly property:** the entire populated rack is a **cartridge** — build, wire, and bench-test it outside the tower, then drop it in as one unit.

**Known geometry risks (test before committing the fleet):**
1. Swing arc: the carrier's **rear-left** corner is the binding one, not the rear-right — it sweeps at the rod-to-rod diagonal about the front-right pivot and must clear the **front-left** station. The rod layout puts it exactly one `Gap` clear of the front-left *rod* at any angle by construction, so the whole question is how much fatter the printed part is than the rod: clearance is `Gap - WallThickness`, currently 2.0 − 2.5 = **−0.5 mm**. Either the gap grows or the wall shrinks. Sets minimum rod spacing vs carrier depth. *Measured on the model:* no longer bites. The posts are clear of it entirely — their openings face the diagonal and they sit above the carrier anyway — and the pads are cut back to a measured opening with 2° of relief, so swept a degree at a time through 45° the carrier and its board touch nothing. The −0.5 mm remains the reason the pads are as small as they are.
2. Hand clearance: reaching the rear-right latch between bays at the 30 mm compute pitch. Escape hatch: front-actuated pushrod along the carrier edge.
3. Printed bore fit on 6.35mm rod: coupon-test printed bore (start 6.5mm, ream to slip fit). Bay base and bay post are both modelled on the nominal rod with no clearance and carry a `RodClearance` parameter for exactly this test. **Bore still open** — designed and printable, not yet coupon-tested. The post adds a second question the bead did not have: a 225° collar has to *clip* onto the rod, so its bore wants a snap fit where the base's wants a slip fit.
4. **The v0.3 fit test no longer covers the current parts.** It confirmed the carrier/plate rod-hole interface as it stood then. The model was not built to reproduce that geometry — the rod gap and the front-left rod position both differ — and both files have since been re-exported from it. Carrier and plates still agree with each other by construction (one function places the rods for both), but the pair wants re-cutting in plywood before the fleet is committed.

## 5. Decision

**v1 = Concept C**, pending the three geometry tests above. Concept B is the fallback (its carrier, material, and detent work transfers 1:1). Concept A stays a bench curiosity.

---

## 6. Carrier material study

| Material | Method | Pros | Cons | Verdict |
|---|---|---|---|---|
| PETG print | 3D print | Detent flexures printable-in-place; bosses, tabs, pivot ring free-form | Opaque; layer lines | Workhorse. v1 default |
| **Clear acrylic 3mm** | Laser | **Edge-lights spectacularly** — carrier becomes the LED element; engraving glows; board floats on light | Brittle at hooks/latch; no compliant geometry; pivot bore wears | v1.1 target |
| Smoked acrylic | Laser | Subtle; glows only when lit | Same brittleness | Alternate skin |
| Hybrid: acrylic plate + printed corner blocks | Laser + print | Acrylic glows, PETG flexes and pivots — each material does its job | Two parts, bolted | **Likely end-state** |

**LED integration:** per-bay WS2812B segment aimed into the carrier's polished edge → engraved traces + node glyph glow in status color. The carriers *are* the status display. Engrave on back face for forward glow; polish light-entry edges.

## 7. Latch — wear ladder (lives in the rack, not the carrier)

The carrier's latch feature is a passive notch; all spring/wear geometry is in a **latch variant of the base** — a $0.20 replaceable part, iterated independently of the fleet's carriers. It has to be the base rather than a post: the notch is on the carrier, and the carrier rides in the base's band. Escalate only when the previous rung measurably fails (100-cycle bench test, logged):
1. **v1** — printed PETG cantilever finger + pull tab, tip engaging the carrier notch (~1mm engagement, ramped on the insert side so closing self-latches, square on the release side so opening requires the tab).
2. **v1.5** — finger tip carries a pressed-in 4.5mm steel BB riding the carrier notch — wear moves to the cheap plate edge.
3. **v2** — ball-nose spring plunger (M3/M4 brass, ~$1) threaded into the base body, adjustable preload.

## 8. Cable management (structural + aesthetic)

- Ethernet and XT30 exit toward the **rear/latch zone** — push/pull forces land next to supported corners (R2 by construction). Verify against swing direction in CAD: cables must feed the swing, not fight it.
- **Ethernet runs vertically up the back**, caught by the cable comb on every bay base — eight lanes, one per bay, so a cable is held every 30 mm the whole way up. Built; see §4. One caveat: a bore tangent to the bridge puts the cable 0.675 mm inside the top and bottom plates' rear edge, so those two plates want a shallow scallop at the eight lane positions (not yet modelled).
- **Power runs vertically up the left**, on the matching comb on the same bay base — again eight lanes, one per bay, each holding the node's bonded red/black pair on edge. Built; see §4. Bigger caveat than the ethernet one: the plates are rectangles and the left web runs on the rack's diagonal, so **the plates overhang the whole power comb** — from 3.6 mm at the front clip to 19.4 mm at the rear one. The eight leads therefore need slots cut through the bottom plate rather than a scallop nibbled out of its edge. Free on a laser and not yet modelled; until then the leads have to be dressed round the outside of the bottom plate.
- Slack loops sized to run out *before* the swing completes if still plugged — forgetting a cable stops rotation instead of ripping a connector.
- SD slots face the open front-right side; card swaps never disturb cables.

## 9. Stretch — per-bay power buttons

One recessed momentary button per bay, mounted on the rack (button-mount post), wired into the bay's power harness.
- **Pi 5 nodes:** J2 header (dedicated 2-pin) — momentary = graceful shutdown; press while halted = **power on**. No GPIO consumed.
- **Pi 4/3 nodes:** GPIO3 + GND with `dtoverlay=gpio-shutdown` — identical semantics incl. boot-from-halt. (GPIO3 = I2C1 SCL, unused.)
- **Harness:** one 4-pin bay connector (5V, GND, BTN, GND) or XT30 + 2-pin JST — decide before crimping the fleet.
- **Cluster-graceful everywhere, zero wiring:** fleet-wide systemd shutdown hook (self-cordon + drain, timeout) ordered before k3s stop. Every shutdown path — bay button, CLI, master toggle (main doc §4.4) — becomes cluster-aware; face node's master sequence simplifies to "trigger each node's own hook, in reverse order."
- **Theater:** buttons double as per-node boot buttons — press a bay, watch its carrier fade up to cyan.
- **Toddler-class threat model:** recess, don't hold-to-activate (long hold on J2 is *force* off — don't train the dangerous gesture).

## 10. Open questions for CAD session

1. Measure: Pi 5 + X1001 stack height w/ standoffs; SD slot clearance vs carrier plane; XT30 pigtail exit; J2 header position on Pi 5.
2. Swing-arc check: rod spacing vs carrier depth so rear-right corner clears rear-left stack (mockup first — this can kill the concept).
3. Hand/latch clearance at the 30 mm compute pitch; pushrod fallback geometry if cramped.
4. Printed bore fit on 6.35mm rod — coupon 6.4/6.5/6.6mm, and a second ladder for the post, whose 225° collar has to clip on rather than slip on. (Carrier pivot bore fit confirmed by the v0.3 initial fit test — no longer open.)
5. Stack tolerance: measure a 10-bay batch stack height (base + post each contribute); size the compliant top post accordingly.
6. Detent engagement depth for PETG finger — coupon 0.3/0.4/0.6mm.
7. Carrier outline: full plate vs skeletal vs acrylic — one of each behind glass with an LED before fleet commit.
8. Rod length + plate pocket depth vs frame interior height; cartridge drop-in clearance.
9. Bay button: recessed panel-mount part that fits a button post; J2 mating connector part number (1.0mm pitch — verify).

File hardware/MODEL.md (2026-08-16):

# The parametric model

The rack is generated, not drawn. A suite of Python scripts builds the whole
assembly inside FreeCAD from one set of parameters, and the fabrication files
in the part folders are **exports from that model** rather than hand-authored
drawings.

This does not change the project's rule that [fabrication is specified by
requirement, not by tool](README.md#fabrication-is-specified-by-requirement-not-by-tool).
It sharpens it: the model *is* the requirement now, and the `.svg` and `.stl`
files are the conveniences. Where the two disagree, the model wins and the
export is stale.

## Running it

```
freecadcmd hardware/generate_rack.py
```

writes `complete_rack_assembly.FCStd` next to the script. Every generator also
runs on its own — `freecadcmd hardware/rack/bay_base_generator.py` and so on —
though the ones that need a board to measure against will say so and stop if
the document has no `Parametric_PCB` in it.

In the GUI, open `generate_rack.py` as a macro. It rebuilds into the existing
document rather than replacing it, so the 3D view keeps its camera across
rebuilds. From the Python console the same thing, re-runnable:

```python
import sys, importlib
sys.path.append("/path/to/aries-28/hardware")
import generate_rack

def reload():
    importlib.reload(generate_rack)
    generate_rack.build_rack_assembly()
```

`generate_rack` reloads every other generator on import, `hardware_utils`
first, so edits to any of them take effect on the next `reload()`.

### A saved .FCStd is not parametric on its own

FreeCAD 1.1 refuses to import a document's proxy modules on restore unless
they come from FreeCAD itself or an installed addon:

```
PropertyPythonObject::Restore: blocked import of module 'rack.bay_base_generator'.
Only modules from FreeCAD or installed addons are permitted.
```

Reopen `complete_rack_assembly.FCStd` without arranging for that and the parts
keep their shapes but lose their behaviour — change a parameter and nothing
moves. Exposing `hardware/` as a Mod directory fixes it:

```
ln -s /path/to/aries-28/hardware ~/.local/share/FreeCAD/Mod/aries_hardware
```

With that in place the proxies rebind and the saved file is fully live. Without
it, treat the `.FCStd` as a snapshot and re-run the script to change anything.

## What it builds

`generate_rack.py` assembles eight bays with boards in the bottom six
(`BAY_COUNT` / `OCCUPIED_BAYS` at the top of the file).

| Generator | Builds |
|---|---|
| `carrier/rpi5_generator.py` | A real Raspberry Pi 5, from its mechanical drawing. **This is the board the rack builds, and the parameter source for everything else.** |
| `carrier/pcb_generator.py` | The old stand-in: a plain 85×56 slab and a block for its ports. Not built by default — see below. |
| `rack/rods_generator.py` | The four support rods, and the rod diameter/gap every other part reads. |
| `rack/rack_plate_generator.py` | The top and bottom plates. |
| `carrier/carrier_plate_generator.py` | The carrier: hook on the left, fork on the right, spacer bosses for the board. |
| `rack/bay_base_generator.py` | The bay base — the bridged bottom of a bay, and the part the carrier rides in. |
| `rack/bay_post_generator.py` | The bay post — one of the four collars that fill the rest of a bay. |
| `hardware_utils.py` | Everything the parts must agree on: rod placement, hole positions, plate proportions, fillet sizes. |
| `carrier/animate_carrier.FCMacro` | Swings one bay's carrier and board out, to check the mechanism. GUI only. |

### The board is a real Pi 5

`carrier/rpi5_generator.py` builds an actual Raspberry Pi 5 — outline, six
holes, connectors, headers and package footprints — from Raspberry Pi Ltd
drawing RP-008347-DS-1, and that is what stands in each bay. It doubles as the
parameter source: it exposes `Width`, `Length`, `Thickness`, `HoleDiameter` and
the four hole offsets under the same names the rest of the model reads, and its
object is named `Parametric_PCB` because that is the name they look a board up
by. Its own holes come from `hardware_utils.mounting_hole_centers()`, the same
call the carrier stands its bosses on, so the two cannot drift apart.

`pcb_generator.py` is the plain slab it replaced. Nothing builds it now, but it
still runs, and step 1 of `generate_rack.py` says how to put it back — worth
keeping for the day a bay has to carry something that is not a Pi.

Modelling the real board is what makes bay clearances answerable, because a Pi
has parts a slab does not: a microSD socket under the laminate, connectors past
three edges, and 15.8mm USB stacks reaching into the bay above. As built, a
seated board clears every one of the rack's other parts — nearest approaches
are 1.0mm from a connector to a post, 1.5mm from the microSD socket to its own
carrier, 3.7mm from a connector to a rod, 3.8mm to the base overhead and 6.8mm
to the carrier overhead.

Its footprints are the drawing's own vector geometry rather than its printed
callouts, so they carry more decimals than the callouts show, and they agree
with every callout to within 0.01mm. Two things in it are *not* from the
drawing and are marked in the source: the heights of packages the side view
never elevates, and how wide the microSD socket is along y.

The parts are grouped one object per material so the board comes out looking
like a board — green laminate, nickel shells, gold pins, black packages. That
grouping is only for the 3D view; the drawing says nothing about materials.
Since colour is a view property, a `.FCStd` built by `freecadcmd` carries none
until it is opened in the GUI — run `rpi5_generator.apply_colours()` there.

Rod placement lives in `hardware_utils.calculate_rod_centers()` and nowhere
else. Three rods sit tight against the board's footprint; the front-left one is
pushed further out so the carrier's hook clears the rear-left rod as it swings.
That offset is the mechanism — see the docstring for the derivation.

## How the parts depend on each other

Two parts are built as a **master parked off the rack plus a clone in it**,
which looks like indirection until you try to remove it:

- **`Blade_Original`** sits to the +x side, `Blade_BayN` clones in the bays.
- **`Carrier_Original`** sits in front of the rack and is hidden, `Carrier_BayN`
  clones in the bays.

A third master is parked but never used in place for a different reason:

- **`Bay_Post_Original`** sits in front of the rack and is hidden; four
  `Bay_Post_BayN_*` clones stand in each bay.

The carrier's split is load-bearing. The bay base is carved by the carrier's
solid, while the carrier's seat height comes from the base's web. Pointed at
one object those two would be a dependency loop and FreeCAD would refuse to
recompute at all. Split, it runs one way:

```
Carrier_Original  ->  Bay_Base  ->  Carrier_BayN
                             \->  Bay_Post  ->  Bay_Post_BayN_*
```

The base takes the master's *profile* and seats it on its own web, so it never
reads where the master is parked — move it anywhere and the carve is unchanged.

**Do not point the base's `Carrier_Plate` link at a clone**, and do not give
the master a placement that depends on the base. Either closes the loop.

Everything flows outward from `Bay_Base`, and that is deliberate: the post
takes its height, wall, bore clearance and key size from the base by
expression, because those are exactly the numbers the two parts have to agree
on for a key to drop into its hole. The post never feeds anything back.

Post *placement* is parametric too. `Bay_Base` publishes its four rod centres
as a read-only `RodCenters` property and each post clone reads its own off it
(`Bay_Base.RodCenters[2].x`), so moving the rods moves the posts. Only the
rotation is written out, since which way a post faces is a design constant and
not something the board size can change.

## The bay base and the bay post

A bay is one base plus four posts. Splitting them is what lets the whole thing
be simple: the base is the part with all the geometry in it, and it is only
6 mm tall; the post is a plain collar, and it is the only part that changes
with the pitch.

**Bay base** — the bridged bottom of a bay:

| | |
|---|---|
| Bay pitch | 30 mm — the base plus one post; the number the rack is specified by |
| Webs | 3 mm, tying the four rod stations into one printed part |
| Landing pads | 3 mm tall, set from the carrier's own thickness |
| Pad relief | 2° trimmed off each end of the measured opening |
| Discs | two rod diameters across, so the key holes have material round them |
| Key holes | 2.4 mm × 1 mm, blind, one per station |
| Wall | 2.5 mm |
| Bore | on the nominal rod, no clearance |

The carrier rides in the pad band, resting on the webs and captured from above
by the posts' feet. The webs and the discs are untouched by any of this — the
carrier is above them, and nothing is ever cut with the carrier's solid at all.

A **landing pad** stands at each station in that band, and it is what a bay
post stands on. A pad is a plain sector of the tube: bore, outer wall, two
straight radial cuts, four rounded corners — 1.0 mm against the outer wall,
0.5 mm against the bore.

It is deliberately **not** the shape the carrier leaves. Cutting the pad to the
carrier's own silhouette is the obvious thing to do and it is a trap: the
carrier's outline is all fillet arcs and its fork slots run tangent to the rod,
so the pad comes out a crescent that tapers to knife points against the bore
with nothing on it a rolling ball can round. Half the corners then cannot be
filleted at all, and a fillet forced into one of the tangent points runs away
along the feather and eats most of the pad.

So the carrier is **measured, not cut with**. `_clear_arc` samples how far round
the station the carrier is absent — through the wall, at three radii — and the
pad is that arc less `PadRelief` off each end. At the pivot the whole
`SwingAngle` comes off the leading end as well, since the carrier has to sweep
out through there. What that gives up is a little area; what it buys is a shape
that is trivial to build, to fillet, to print and to think about.

The base does **not** change with the pitch, so there is one `rack-bay-base.stl`
for both the 30 mm and the 42 mm rack.

### The cable combs

Two of them, one per run. Both are rows of clips a cable is pressed into and
stays in, both are eight wide because the bottom bay's comb has to pass every
bay's cable, and both put the face they hang off directly behind every clip so
none of their depth is spent on a wall that is already there. They differ in
what they carry and in how far up the base they reach.

#### Ethernet, off the back of the rear bridge

| | |
|---|---|
| Clips | 8 — one per bay, since the bottom bay's comb passes every bay's cable |
| Bore | 7/32 in (5.556 mm), the cable itself |
| Mouth | 5/32 in (3.969 mm), so the clip wraps 269° and a cable has to be pressed in |
| Between clips | 1/8 in (3.175 mm), and half that outboard of the two end ones |
| Depth | 6 mm proud of the bridge |
| Height | 6 mm — the full thickness of the base, not just the bridge's 3 mm |
| Backing | a beam rod-centre to rod-centre, forward to the line tangent to both rear bores |
| Offset | 15.15 mm from the base's right edge to the right end of the comb |

Each bore is **tangent to the back of the bridge** rather than standing off it,
which is what keeps the comb shallow: the bridge is the back wall of every
clip, so the 6 mm buys the cable plus the horns either side of the mouth and
nothing else. Those horns come out 1.3 mm thick, and everything the cable can
touch is rounded — 0.5 mm on each horn tip and on the barb behind it, 1.0 mm
on the comb's two ends.

The comb stands the **full thickness of the base**, so its clips are as tall as
the bay's landing pads rather than only as tall as the bridge — and standing
that tall, its upper half sits in the band the carrier rides in with only a 3 mm
web under it. So it is backed by a **beam**: rod centre to rod centre, forward
to the line tangent to both rear bores, which is as far in as anything can reach
without eating into a rod. Below the pads that beam is buried in the bridge and
does nothing. Through the pad band it is the root the comb cantilevers off, and
it swallows both rear landing pads on the way, which is what carries the comb's
load into the rest of the base. It also turns the back of the base into a
full-height beam rather than a 3 mm web, which the rack gets for free.

The carrier's own deepest reach is at rest, and it only moves forward as it
swings, so that tangent line keeps one rod radius (3.175 mm) of clearance at the
worst moment.

Six corners come out of all that, and all six are rounded at 1.0 mm:

| Where | |
|---|---|
| Beam into a rear pad | 2 — one per pad, on the inboard side; the beam stops at the rod centres, so the outboard crossings are past its end |
| Comb's left end | 2 — stacked, because the base's outline steps there: the disc reaches furthest back below the pads, the pad above them |
| Comb's right end | 1 — the shoulder where the comb stops and the beam carries on |
| Bridge onto the rear-right disc | 1 — pre-existing, and the shallowest of them at 153° |

Two things had to be got right for those to take at all. They are filleted
**after** the refine, not before: the same fillet that fails on the 240-face
solid the booleans leave takes cleanly on the 130-face one. And the two at the
comb's left end go bottom-first, since rounding the upper one drags the lower a
few hundredths sideways — far enough that looking it up by position afterwards
finds nothing.

The whole row lands on the rear bridge with nothing overhanging. 8 clips need
66.7 mm of the bridge's 78.7 mm, so the offset is what is left after the end
walls: at more than 15.15 mm the row runs off the left end.

#### Power, on the left web

The node's XT30 pigtail is a bonded red/black pair, and it is carried **on
edge** — one lead behind the other rather than side by side. So a clip here is
not a bore but a **stadium**: two wire diameters long, one wide, standing normal
to the web, with the inner circle tangent to the web's face and the outer one
tangent to that in turn. The pair drops in the way it comes off the reel, red
inboard against the web and black outboard behind it.

| | |
|---|---|
| Clips | 8 — one per bay, as on the ethernet comb |
| Wire | 3/32 in (2.381 mm) per conductor |
| Pocket | 2.381 × 4.763 mm — one wire wide, two deep |
| Mouth | 2.143 mm, 90% of the wire, so the lip a lead is pressed past is 0.12 mm |
| Between clips | 1/8 in (3.175 mm), and half that outboard of the two end ones |
| Depth | 6 mm proud of the web, leaving 1.24 mm of horn |
| Height | 3 mm — the web band, and nothing above it |
| Backing | none |
| Position | centred on the web; 44.45 mm of clips on a 72.58 mm face |

Nothing pinches between the two wires — the pocket's waist is its full width.
That is not an oversight: the pair is bonded, so it cannot be separated to be
threaded in a lead at a time, and a waist would only be something to fight.
The mouth is looser than the ethernet comb's 71% for the same reason it can
afford to be: the web is the back wall, these leads are lighter than a patch
cable, and the clip is a keeper rather than a clamp.

**Where the ethernet comb had to be beefed up, this one does not.** The
ethernet comb stands into the band the carrier rides in, which is why it needs
a beam. The power comb never leaves the web, so the web is its backing and the
carrier never sees it — swept a degree at a time through the full 45°, the
comb costs the swing nothing.

The left web runs on the rack's diagonal rather than square to anything, so the
comb is worked in the web's own frame — `u` along the face from the front-left
station towards the rear-left, `v` out of it — and `_at`/`_place` are the only
two things that know the difference. Being centred, it starts at u=14.07, well
clear of the two stations' discs, which only reach past the face for u<2.85 and
u>69.73.

Two corners come out of it, where the comb's ends run back into the face of the
web, and both are rounded at 1.0 mm.

**Bay post** — one of the four collars above it:

| | |
|---|---|
| Height | 24 mm — the pitch less the base, so this is what a pitch change moves |
| Wrap | 225° round the rod |
| Wall | 2.5 mm |
| Key | 2.4 mm × 1 mm stub on top, one per post |
| Bore | on the nominal rod, no clearance |

All four posts in a bay are the same part; only the rotation differs. Each
turns its opening onto the rack's diagonal, which does two things: the wall
wraps the outside of the stack rather than the board side, and wrapping more
than half the rod means a post clips on instead of being threaded over the end
of one. The key stands proud of `Height` and drops into the base above, so the
pitch is unaffected by how tall it is.

That opening is what retired the old bead's board clip: where the bead's full
tube overhung the board by 0.5 mm, a post's nearest wall stands 1.0 mm off it.

#### The rear-right post is not the same part

It carries one **ethernet clip** on its back, so a bay uses three of the plain
post and one of this. Same generator, one flag (`CableClip`), and
`generate_rack.py` keeps two masters and links the RR station to the second.

The post is built with its opening on +x, so its back is −x — and once it is
turned onto the rack's diagonal that back faces 45° out of the rear-right
corner, which is where the run turns out of the base's comb and heads for the
node.

**The clip is revolved about the post's own axis, not extruded off it.** That
is the whole design. A C is drawn in the meridian plane — bore circle, outer
circle, both concentric, the two ends of the C closed off with semicircular
caps — and swept 30° round the post, 15° either side of its back. What comes
out follows the collar instead of being a block stuck onto a cylinder, and it
has no corner on it anywhere: every boundary of the profile is an arc, and the
caps are tangent to both circles by construction, their radius being half the
wall and their centres sitting on the mid-radius.

| | |
|---|---|
| Bore | 7/32 in (5.556 mm), as on the base's comb |
| Mouth | 5/32 in (3.969 mm), opening radially outward |
| Wall | 2.0 mm, which also sets the 1.0 mm cap radius |
| Wrap | 255.7° — the cap angle falls out of the mouth, not the other way round |
| Sweep | 30°, giving 4.4 mm of grip along the cable |
| Height | 0 → 9.56 mm, tangent to the post's bottom face |
| Cost | +115.6 mm³ |

Two things follow from putting the **bore tangent to the post's outer shell**.
The cable rests on the collar; and the C's back wall lies *inside* the collar's
own wall, so the two merge on the fuse and the collar is the back of the clip
for free — the same trick the base's combs play against the bridge and the web.
That is also why `ClipWallThickness` is 2.0 rather than the post's own 2.5: at
2.5 the C's back would land exactly on the rod bore, and the fuse would be two
solids sharing a face. At 2.0 it stops 0.5 mm short of it.

**Nothing is cut from the post.** The channel and its mouth are holes in the
revolved profile, not cuts into the collar, so the clip is purely fused on and
the 225° collar is untouched underneath it.

One consequence of revolving: the channel is an arc, not a straight tube. Over
30° at a centreline radius of 8.45 mm the arc stands 0.29 mm off its own chord,
so the straight-through aperture is about 5.27 mm rather than the bore's 5.556.
A patch lead will take that up — it is a clip, and the squeeze is grip — but a
full-fat 6 mm jacket would want the bore opened by that much.

## Known gaps

Recorded here rather than in the part READMEs, since they are properties of
the model:

- **The top plate's key holes are not modelled.** The rods are sized to the
  stack exactly, so the plate lands where the posts end and the topmost bay's
  four keys stand 1 mm into it. The plan is four blind holes in the top plate
  only, drilled by hand rather than cut — see `docs/rack-design.md` §4. Until
  they are added the model shows that interference, and the plate would sit
  1 mm proud in reality.
- **45° is the relief, not a proven extraction.** Swept a degree at a time
  through 45°, the carrier and its board clear every pad and every post with
  nothing touching — but whether the hook clears the left rods far enough to
  then lift the carrier away has not been worked out.
- **The cable runs clip the top and bottom plates by 0.675 mm.** A bore
  tangent to the bridge puts the cable's near edge at y=66.85 and the plates
  reach y=67.525, so each of the eight cables overlaps a plate corner by
  5.0 mm³ where it passes. Only at the two plates — the bays themselves are
  clear — and a cable will deflect round it, but the tidy fix is a shallow
  scallop on the plates' rear edge at the eight clip positions, which is not
  modelled. Moving the comb back 0.7 mm would also do it, at the cost of the
  tangency.
- **The plates cover the power comb outright.** The plates are rectangles on
  the rod bounding box and the left web runs on the rack's diagonal, so the
  plate's left edge sits outboard of the whole comb — the eight lanes are
  3.6 mm under it at the front clip and 19.4 mm at the rear, and even the
  comb's furthest-out corner is 1.38 mm inside the edge. So this one cannot be
  fixed by nibbling the edge the way the ethernet one can; it wants eight
  **slots** through the plate, on the comb's own axis. Only the bottom plate
  actually has to pass anything, since the runs come up from the facilities
  deck and terminate at their bays. Free on a laser, not modelled, and until it
  is the leads have to be dressed round the outside of the bottom plate.
  Backing the comb off is not an alternative here: there is no depth of comb
  that gets clear of a plate that overhangs it by 19 mm.
- **Two posts stand mostly on the carrier, not on their pad.** A post's foot is
  a 225° annulus and the carrier leaves it far less than that to stand on: the
  rear pair land 93–99% on pad, but the front-right is at 32% and the
  front-left at 18%. The rest of each foot rests on the carrier plate, which is
  what captures the carrier — but it also means pulling a carrier out drops the
  stack above onto whatever pad is left. Accepted for now: a post carries only
  the stack's own weight. Whether the foot should be trimmed back to the pad
  has not been decided.

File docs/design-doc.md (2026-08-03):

# Project Aries 28 — Design Document

**A tower-format Raspberry Pi cluster: a mini private data center and a k3s learning platform.**
Version 0.5 — July 2026

---

## 1. Mission & Non-Goals

**Mission:** Build an ARM Linux cluster in a desktop-tower-style enclosure — starting from a single working node and growing to a full single-box fleet (the enclosure has 10 node bays; today's build populates seven), with further growth by adding boxes rather than rebuilding (see `network-design.md` §6). It serves as (a) a private cloud (storage + hosting), (b) a hands-on Kubernetes/infrastructure learning platform, and (c) a display piece with live status visualization and a front-panel dashboard screen.

**Non-goals:** Production reliability guarantees, performance competitiveness with x86, minimizing cost at the expense of learnability. This is a toy with a curriculum.

**Cost:** full from-scratch replication is roughly **$984–$1,164**, and varies heavily with current market pricing — this specification was priced during a period of elevated RAM/storage prices (see the BOM in §7). Existing hardware reduces the total; the from-scratch figure is the reference for a complete build.

**Lessons embedded in the design (the real deliverables):**
1. k3s from single-server to a redundant control plane (embedded etcd, quorum) — node-level fault tolerance; the migration itself is a lesson
2. Distributed storage (Longhorn) and what happens when a node dies
3. Routing/NAT/DHCP/DNS (the gateway is a mini-course in networking)
4. Infrastructure as Code + GitOps (the cluster state lives in git)
5. Power distribution, fusing, and voltage-drop calibration (real electrical design)
6. Node lifecycle: provisioning, draining, replacing, recovering
7. Resource scheduling on heterogeneous nodes (1GB/2GB/4GB mix makes requests/limits real)
8. Backup discipline: one storage node = one replica = off-tower backup from day one (Restic)
9. Power sequencing: orderly fleet shutdown via self-holding soft-power circuit (Phase 6)

---

## 2. Architecture Overview

### 2.1 Logical topology

```
Internet / Home LAN
        │
   [WAN keystone on panel]
        │
   ┌────┴─────┐
   │ GATEWAY  │  aries-gw   (router, DHCP, DNS, WireGuard — NOT in k3s)
   └────┬─────┘
        │ 10.28.0.0/24 (private cluster subnet)
   ┌────┴───────────────────────────────────┐
   │      8-port managed GbE switch         │
   └─┬────┬────┬────┬────┬────┬─────────────┘
     │    │    │    │    │    │
   cp-1 cp-2 cp-3 wk-1 st-1 face
   └─ servers+workers ─┘      └ LED/kiosk, outside k3s
```

- **Subnet:** `10.28.0.0/24`. Gateway static `.1`; control-plane reservations `.11–.13`; `.100+` dynamic pool for all other nodes and maintenance devices (agents named via `*.aries.lan` DNS). See `network-design.md` §4.
- **Naming:** `aries-gw`, `aries-cp-1..3`, `aries-wk-*`, `aries-st-*`, `aries-face`.
- **Ingress:** all external traffic via gateway; port-forward or WireGuard only. Cluster invisible to home LAN by default.
- **DNS:** dnsmasq on the gateway resolves internal names on the cluster subnet — `*.aries.lan` (nodes by hostname; services via the ingress). Home-LAN and internet access use separate naming scopes (`*.athome.example.com` and the public domain) — see `dns-and-exposure.md` §1.1.
- **No WiFi anywhere inside the box.** The face node uses a USB-ethernet adapter.
- **VLAN plan (managed switch, TL-SG108E):** VLAN 10 cluster, VLAN 20 face/kiosk, VLAN 99 MAINT; gateway port trunked, router-on-a-stick between them. Port mirroring to MAINT = live Wireshark classroom. Switch management IP moved from factory default into `10.28.0.0/24` at first boot.

### 2.2 Fleet

| Node | Board | Role | RAM need | Storage |
|---|---|---|---|---|
| aries-gw | Pi 4 1GB + USB3-GbE adapter | Router, DHCP, DNS, WireGuard, netboot (Ph.4) — two NICs: onboard Ethernet to the internal switch trunk, USB3-GbE to WAN (see `network-design.md` §5.2) | ~512MB | microSD |
| aries-cp-1 | Pi 5 2GB | k3s server (embedded etcd) + worker; **current build** — also carries interim storage duty (Longhorn/Nextcloud) until st-1 is added | ~2GB | microSD (OS) + **NVMe 256GB** (etcd + interim data) |
| aries-cp-2, aries-cp-3 | Pi 5 2GB | k3s server **and** worker — Phase 3+ HA joins, not yet built | ~2GB | microSD (OS) + **NVMe** (etcd)* |
| aries-st-1 | **Pi 5 4GB** | k3s agent, storage-labeled; Longhorn, Nextcloud/MinIO — **planned addition**; takes over the bulk-storage role from cp-1's interim NVMe once built | 4GB | **NVMe 256GB** (1TB-class upgrade later) |
| aries-wk-1 | Pi 4 1GB *(pending autopsy)* | light worker | 1GB | microSD |
| aries-face | Pi 3A+ + USB-ethernet | LED daemon + 7" kiosk dashboard — outside k3s | 512MB | microSD |
| bays 8–10 | empty, engraved covers | expansion | — | — |

*Every k3s server gets NVMe, not just the storage node — SD is not recommended for etcd's constant small fsync writes (see `node-setup.md` §2). cp-1 is the only server today, so it carries the fleet's one NVMe and, until a dedicated st-1 exists, also hosts the Longhorn/Nextcloud data that will eventually move to st-1. cp-2/cp-3 arrive with their own NVMe when Phase 3+ HA is built (§2.3, §4.3); their split is etcd-heavy (small data partition) since bulk storage lives on st-1 by then.

Why the face node is outside the cluster: the monitor must survive what it monitors. It polls the k3s API over wired ethernet (USB 2.0 adapter, ~300Mbps — irrelevant for API polls and pixels).

### 2.3 Control plane strategy

k3s servers run workloads by default — there are no dedicated "dead weight" masters. The HA tax is only ~600–900MB of RAM per server for k3s + etcd.

**Phase 1:** single server (cp-1) + agents. cp-1 carries the fleet's only NVMe today (etcd partition + an interim data partition standing in for st-1 — see §4.3). **Phase 3+:** migrate to 3-server embedded-etcd HA (k3s supports `--cluster-init` migration); cp-2 and cp-3 each get their own X1001 + NVMe for etcd when they join, since SD is not recommended for etcd's write pattern — the fleet doesn't stay on a single NVMe once HA is built. etcd requires majority quorum: 1 server = SPOF, 2 = worse than 1, 3 = any single node can be pulled live. The "yank a control-plane carrier while Nextcloud keeps serving" demo is the graduation exam.

---

## 3. Physical Design

### 3.1 Frame — 2020 aluminum extrusion

Stock: **10× 600mm black anodized 2020** (VEVOR kit, ~$42).

Cut plan (minimizes cuts, keeps compactness):
- **4× verticals @ 450mm** (cut 4 pieces; 150mm offcuts become internal rail supports)
- **4× width horizontals @ 250mm** and **4× depth horizontals @ 350mm** (cut 4 pieces into 250+350 each — zero waste)
- **2 spare full-length pieces** for mid-height rack supports / shelf supports / mistakes

Resulting envelope ≈ **450 (H) × 290 (W) × 390 (D) mm external** (250/350 inner rails + 2020 profile) — a compact mid-tower, roughly half the volume of the 600mm no-cut option. Printed corner brackets or cast corner cubes; T-nuts throughout.

Cutting notes: miter saw with non-ferrous blade or fine-tooth hacksaw + miter box; deburr ends; square cuts matter for corner brackets.

Two decks, bottom to top (see `architecture.md` §5 for the deck-layer rationale):
1. **Facilities deck** (bottom, full footprint): LRS-200-5, AC inlet, 12-circuit fuse block, ground bus, and the switch rack — 8-port managed switch (second 8-port cascades in here at expansion), patch cables dropping up to the compute deck's carriers. Heavy, static infrastructure kept low for stability and serviceability, displayed as a feature through the panels.
2. **Compute deck** (above): carrier bays in rod-and-bead rack cartridges (see `rack-design.md`) at **two pitches** — a **30 mm compute pitch** for bare/diskless nodes (gateway, light worker, face node) and a **42 mm extended pitch** for nodes with a vertical accessory. The control-plane and storage carriers (Pi 5 + top-mounted X1001 NVMe adapter) live in 42 mm extended bays — now most of the compute fleet, since every k3s server carries an NVMe HAT for etcd (§4.3), not just the storage node. See `architecture.md` §6 for the two-pitch rationale.

Front face reserves a cutout for the 7" display (portrait or landscape — decide in CAD before cutting acrylic). Panel/airflow/thermal/mounting details in §3.3.

### 3.2 Carrier specification (the standard interface)

**Standardize the carrier, not the board.** Fixed spec: outer geometry, rack-interface (rod/bead) engagement, XT30 pigtail position, handle. Per-board variants change only the mounting-hole pattern:
- `carrier-rpi-b.*` — Pi 3B / 4B / 5 (shared 85×56mm footprint, M2.5 holes on 58×49mm — one carrier fits all three B-series generations)
- `carrier-rpi-a.*` — Pi 3A+ (65×56mm, same hole spacing, shorter)
- extensible: `carrier-<board>.*` for any additional board type, added as needed

File naming and per-board detail are authoritative in [`hardware/carrier/`](../hardware/carrier/); see also `rack-design.md` for the mounting mechanism.

Details: PETG body, M3/M2.5 brass inserts, XT30 keyed power pigtail, labeled slim patch cable, node name laser-engraved on handle. Blank engraved covers for empty bays.

**Hot-surgery procedure:** `kubectl drain <node> --ignore-daemonsets` → LED trace amber → unplug XT30 + ethernet → pull carrier. Reverse; `kubectl uncordon`.

### 3.3 Panels & enclosure styling (optional aesthetic layer)

The panel and lighting choices below are one implementation's aesthetic; they are **optional** and not required for a functioning cluster. A build may use plain panels, omit the smoked/clear treatment, or skip lighting entirely without affecting the compute, power, or network design. The functional requirements are only that panels provide the specified openings and that the enclosure allows airflow; everything else in this section is presentation.

**Show faces vs. hide faces.** The enclosure has three display faces and two solid faces — the aesthetic showcases *both* the compute and the power wiring, hiding only the truly-boring cable back and the never-seen bottom.

| Face | Panel | Rationale |
|---|---|---|
| Front | smoked acrylic | Hero face: boards, LEDs, swing carriers, engraved Aries glyph + radiating traces, edge-lit |
| Left (access) | smoked acrylic | Removable/openable — service side; shows the rack |
| Right (power bay) | smoked acrylic | **Power wiring is a feature, not a thing to hide** — exposed Meanwell, dressed red/black leads, fuse block, IEC inlet run, underlit warm amber |
| Back | solid black 3mm | Cable back-of-house; dark backdrop for LEDs |
| Bottom | solid black 3mm | Never seen; structural |
| Top | clear or black | Judgment call — clear to see down into the rack, or black with the exhaust-fan cutout |

**Smoked over clear** on the show faces: reads as deliberate dark-tech, hides minor cable imperfection, and makes LEDs pop against a near-black background (unlit acrylic ≈ black, lit elements glow). Translucent *colored* panels are avoided — they muddy the status-LED colors (a blue wall makes green "healthy" LEDs read wrong); color comes from the LEDs, not the walls.

**The power bay is a featured display.** Because the right panel is transparent: dress the DC wiring as display wiring (sleeved red +5V / black ground in clean parallel runs, held by a printed comb), keep the AC side heatshrinked and tidy (it's now *visible*, so sloppy mains wiring would be on show), and underlight the bay (amber static, or PSU-state-driven). The frame-bond ground lead (§4.2) becomes a visible tidy green wire to a labeled star point — reads as "the builder knows what they're doing." The inlet→fuse→PSU run is a deliberate visual line the eye follows — the opposite of a generic sealed-brick PC PSU.

**Panel material & mounting — 3mm throughout, clip-mounted (not slotted).**
- Use **3mm acrylic everywhere** (widely available, laser-cuttable). Don't fight the 3mm-in-6mm-slot gap: **surface-mount panels onto the frame face with printed PETG retainer clips** that T-nut into the extrusion slot, rather than sliding acrylic into the slot. 3mm is ideal for this, panels sit proud/floating (intentional look), and clips make panels **removable one-handed** — essential on a machine under constant iteration.
- Alternative for an inset look: printed PETG adapter frames (6mm outer to fill the slot, lip + foam tape holding the 3mm pane).
- Gasket/weatherstrip tape (≈1.5mm each side) is the quick legitimate fallback to snug 3mm in a slot and damp fan vibration.
- **At least the front (or left) panel must be removable or hinged** (magnets or printed hinge), so a board can be reached without disassembling the enclosure.
- Black 3mm → back and bottom; smoked 3mm → front, left, and right show faces (cut to size).

**Front panel engraving (brand mark).** Large Aries ram glyph (♈, the validated SVG from the carrier work — third-party artwork under CC Attribution, see `hardware/carrier/README.md`) engraved on the **back face** of the smoked front panel, centered, with cyan circuit-traces radiating outward; LED strip along the panel edge edge-lights the engraving so it glows while the rest stays dark. Motif repeats at three scales: big glyph on the front (logo) · astrometric Aries constellation as a secondary detail (signature) · tiny ram per carrier (texture). 7" display integrated into the trace artwork.

- **Connection panel (rear, laser-cut):** IEC C14 inlet w/ switch+fuse (only power entry), the recessed **DPST soft-power toggle** (§4.4), RJ45 keystone **WAN**, RJ45 keystone **MAINT** (direct switch port, bypasses gateway), optional USB-C keystone (gateway serial console — see `network-design.md` §8.2).

### 3.3.1 Airflow & thermal

- **Intake:** back-left wall CNC/laser-cut with an air-inlet pattern (low, cool-air entry).
- **Exhaust:** 140mm A-RGB fan on **top or right side**, with matching vent holes, blowing hot air out. Vertical boards + rising heat = natural chimney the fan assists.
- **Fan:** ARCTIC P14 Pro A-RGB (140mm, 12V PWM motor + 5V ARGB signal). PWM lets the face node throttle by temperature; ARGB ties into the LED daemon (fan color = cluster state). 12V from a small 5V→12V boost converter (XL6019) off the main rail; ARGB data is the native 5V digital signal.
- **Acrylic thermal limits:** cast acrylic softens ~100–110°C and deforms under load well below that (~80°C practical ceiling). With the fan running, internal air sits ~35–45°C, so under normal operation the boards are the limiting factor: if they are cool enough to run, the acrylic is well within its margin (the Pi 5 throttles ~80–85°C at the chip, long before circulating air threatens the panels). **This holds only while airflow is maintained.** A fan failure removes that assumption — a stagnant hot pocket can form near a carrier, and localized air near a powered board with a heatsink can reach the point where 3mm acrylic sags under the heatsink's weight even though the silicon is still within limits. A fan-failure alert (via the LED/monitoring system) and conservative bay spacing mitigate this; the "boards as thermal canary" rule is a normal-operation guideline, not a fan-failure guarantee.
- **Power-bay thermal rules** (the one hotspot — the PSU is the only real heat source, ~45–55°C case surface at ~80W): keep a **15–20mm air gap** between the Meanwell and any acrylic; **vent the power bay** (slots low + high, or the diagonal-grid vent motif scaled up) so heat rises past the PSU rather than pooling against a panel; don't mount the PSU flush against an acrylic panel.
- **Shed caveat (LA-area, un-A/C):** summer ambient can hit 40°C+, raising every component's baseline. The cluster throttles before the acrylic is threatened, so the boards remain the limiting factor — but plan the vent/fan generously for hot days.

### 3.3.2 Board & PSU mounting

- **Boards sit on 3mm spacers** cut from black 3mm acrylic, on top of the carriers (lifts the board off the carrier for airflow and connector clearance). Spacers cut on the laser from the same black stock as the solid panels.
- **PSU on spacers** (standoffs) rather than flush — a small air gap under the Meanwell for convection and to keep conducted heat out of the bottom panel. (Mounting the PSU directly to the aluminum frame as a heatsink is thermally ideal but mechanically fiddly; spacers are the pragmatic choice — overengineering the frame mount isn't worth it.)
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

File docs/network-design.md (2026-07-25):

# Aries 28 — Network Design

**Companion to the main design doc. Scope: internal cluster network, WAN uplink, addressing, VLANs, and multi-box scaling.**
Version 1.0 — July 2026

---

## 1. Principles

- **One cable in.** The entire box connects to the outside world through a single Ethernet uplink. Everything inside lives on a private, isolated, **wired-only** network. This makes the box portable (plug it into any network and the internals never change) and self-contained.
- **Wired only, no Wi-Fi inside.** Internal cluster traffic — especially etcd — is latency- and jitter-sensitive; Wi-Fi is neither stable nor appropriate. Every node reaches the internal switch by cable. (The one board without built-in Ethernet, the Pi 3A+ face node, uses a USB-to-Ethernet adapter rather than falling back to Wi-Fi.)
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

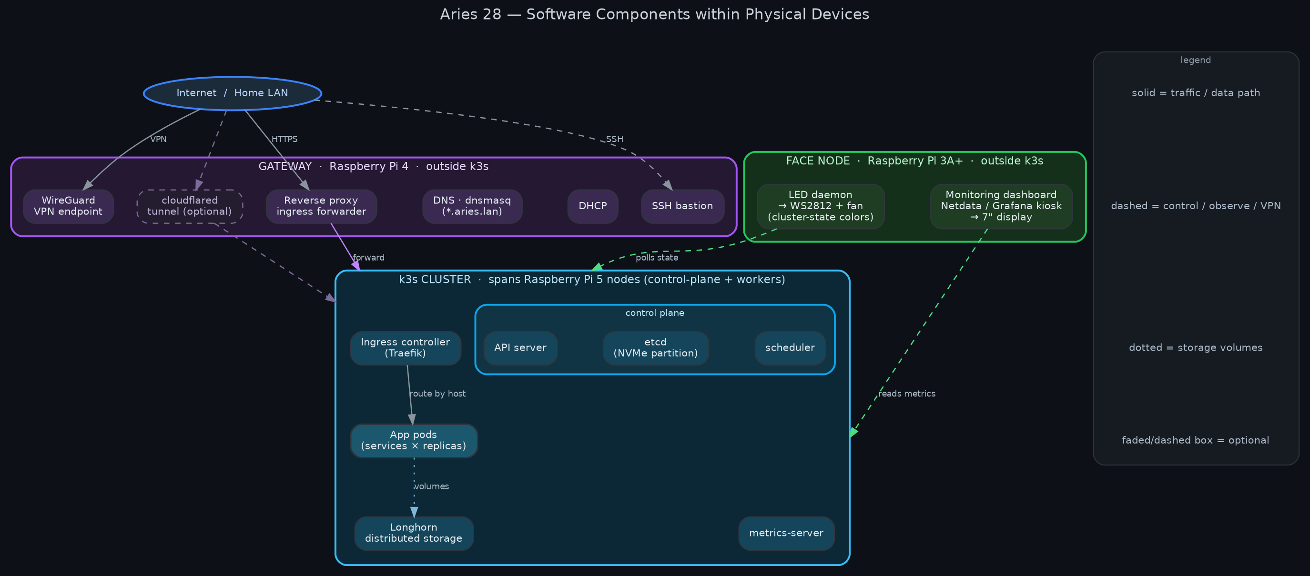
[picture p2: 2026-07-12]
docs/diagrams/software-architecture.png

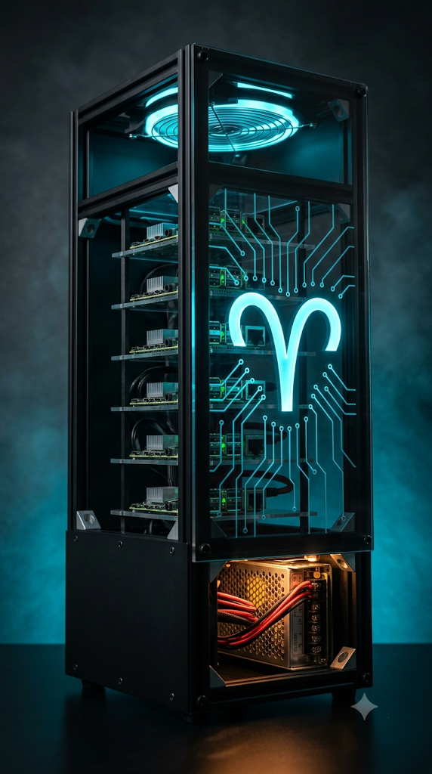
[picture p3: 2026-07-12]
docs/images/aries-28-glyph.png

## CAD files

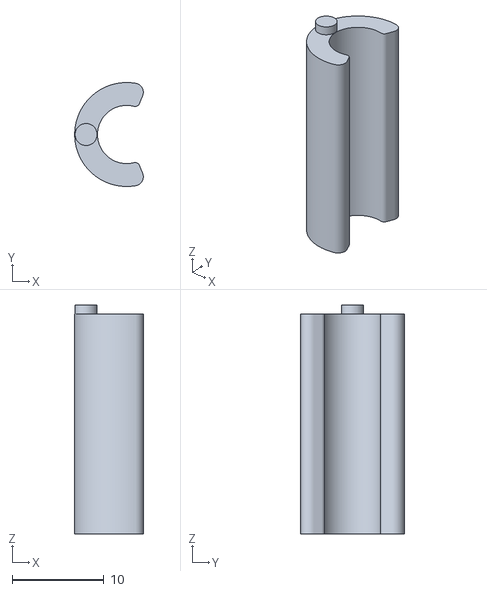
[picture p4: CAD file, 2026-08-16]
hardware/rack/rack-bay-post-30.stl
7.50 x 11.3 x 25.0

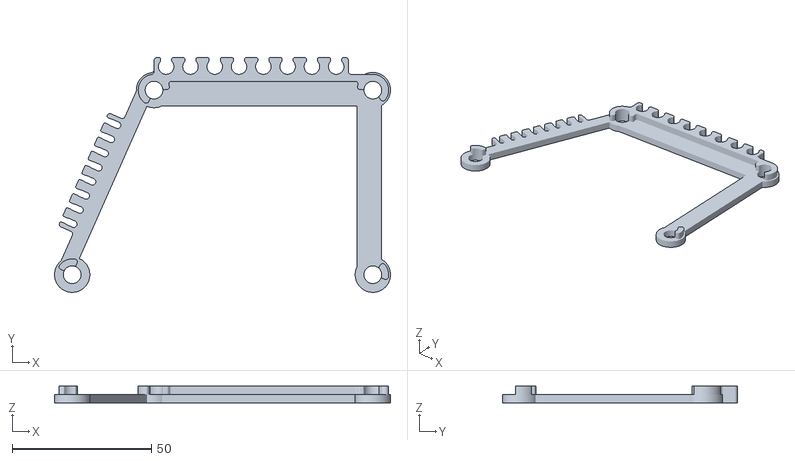
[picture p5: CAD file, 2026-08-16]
hardware/rack/rack-bay-base.stl
120.8 x 84.4 x 6.00

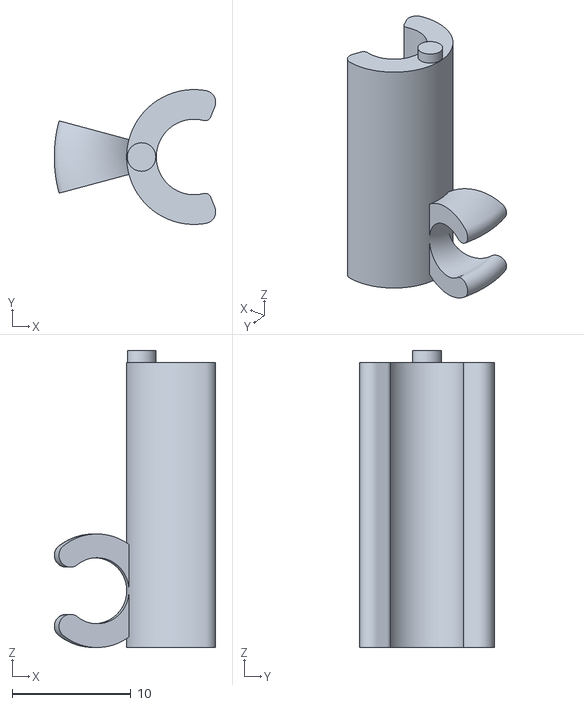
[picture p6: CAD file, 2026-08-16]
hardware/rack/rack-bay-post-rr-30.stl
13.6 x 11.3 x 25.0

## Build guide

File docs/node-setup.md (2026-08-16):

# Aries 28 — Control-Plane Node Setup (k3s + partitioned NVMe)

**Runbook for bringing up a k3s server node on a Raspberry Pi 5 with an NVMe SSD split into etcd + data partitions.**
Version 1.0 — July 2026 · Validated on a practice node (`aries-28-test`, Pi 5, k3s v1.36.2+k3s1)

> Scope: this is the **first server** procedure, prepared for a redundant control plane (embedded etcd via `--cluster-init`, which allows additional server nodes to join for quorum).
> Adding more servers (cp-2, cp-3) or agents (workers) is a follow-on doc; the token location is noted at the end.

---

## 0. Prerequisites & conventions

- Raspberry Pi 5 with NVMe HAT (Geekworm X1001) + NVMe SSD, assembled and detected.
- Raspberry Pi OS Lite 64-bit (or Ubuntu Server), freshly flashed, SSH enabled.
- **Decide the node's role-name before you start** — k3s takes the node name from the hostname *at install time*, and renaming after it joins etcd is painful. Use the fleet convention: `aries-cp-1`, `aries-cp-2`, `aries-cp-3` (control plane), `aries-st-1` (storage), `aries-gw` (gateway, not in k3s).
- All steps assume `sudo`.

Set the hostname first:
```bash
sudo hostnamectl set-hostname aries-cp-1     # adjust per node
```

---

## 1. Kernel boot parameters (cmdline.txt)

Two fixes go on the **same single line**, space-separated, **no newline** (a line break here breaks boot parsing).

File: `/boot/firmware/cmdline.txt` (older images: `/boot/cmdline.txt`)

Append to the end of the existing line:
```
cgroup_memory=1 cgroup_enable=memory nvme_core.default_ps_max_latency_us=0 pcie_aspm=off pcie_port_pm=off
```

Why each is needed:
- `cgroup_memory=1 cgroup_enable=memory` — Raspberry Pi OS ships with the memory cgroup **disabled**; Kubernetes requires it to enforce pod memory limits. Without it, k3s dies at startup with `failed to find memory cgroup (v2)`. **Every node needs this.**
- `nvme_core.default_ps_max_latency_us=0` — forbids the NVMe drive from entering deep power-save (APST) states. Budget drives (Vansuny/Fanxiang-tier) mishandle the wake handshake on the Pi 5 controller, producing `CSTS=0xffffffff` "controller is down" errors. **Storage nodes especially.**
- `pcie_aspm=off pcie_port_pm=off` — disables PCIe-link-level power management (the bus-side companion to the above).

Edit, then **reboot** (cgroup changes only take effect at boot):
```bash
sudo nano /boot/firmware/cmdline.txt
sudo reboot
```

> ⚠️ This file is unforgiving — a typo can prevent boot. Double-check it's still ONE line with a single space before each new parameter.

Optional (SD longevity on SD-booted nodes): install `log2ram` to keep logs in RAM.

---

## 2. Partition the NVMe (GPT: etcd + data)

**Survey first — never wipe the wrong device:**
```bash
lsblk -f
```
Expect `mmcblk0` = SD card (OS), `nvme0n1` = the SSD. Confirm before proceeding.

**Why two partitions:** the split provides **space and filesystem isolation, not I/O-performance isolation** — this distinction matters. etcd is latency-sensitive and performs constant small fsync writes; Longhorn/data performs bulk sequential writes. A separate partition guarantees etcd cannot be starved of capacity (bulk data growth or logs cannot fill etcd's space) and keeps the two filesystems independent, which makes it straightforward to relocate the data volume to a separate physical device in a later revision. It does **not** isolate I/O contention: both partitions share one NVMe controller, one command queue, one NAND, and the single PCIe lane, so if bulk I/O saturates the controller's queue depth, etcd's fsync latency can still spike regardless of the partition boundary. True performance isolation requires a separate physical device or cgroup-level (blkio) IOPS limits. The partition split is chosen here as the low-cost step that makes that later separation easy, not as a performance guarantee. etcd is small in practice (hundreds of MB); 8 GB is generous, so the split is deliberately lopsided: small etcd, large data.

```bash
# clear any remnants from earlier attempts
sudo wipefs -a /dev/nvme0n1

# GPT label + two partitions
sudo parted /dev/nvme0n1 --script mklabel gpt
sudo parted /dev/nvme0n1 --script mkpart etcd ext4 0% 8GB
sudo parted /dev/nvme0n1 --script mkpart data ext4 8GB 100%

# filesystems + labels (mount by label -> survives device renaming)
sudo mkfs.ext4 -L aries-etcd /dev/nvme0n1p1
sudo mkfs.ext4 -L aries-data /dev/nvme0n1p2
```

> **Storage node vs cp node:** on a pure control-plane 2 GB node you barely need the data partition — etcd is the point. On the 4 GB storage node the data partition is the large Longhorn/Nextcloud volume. Adjust the 8 GB split only if you have a reason; it's fine as-is for both.

> **Note for Longhorn:** Longhorn can take a mounted directory (what we do here) or a raw block device. If you later decide to give Longhorn the raw device, don't format the data partition. For this runbook we use a mounted directory at `/mnt/data`.

---

## 3. Mount points + fstab

etcd's default k3s location is `/var/lib/rancher/k3s/server/db` — we mount the etcd partition there so etcd lives on the SSD from the very first start.

```bash
sudo mkdir -p /var/lib/rancher/k3s/server/db /mnt/data

echo 'LABEL=aries-etcd /var/lib/rancher/k3s/server/db ext4 defaults,noatime 0 2' | sudo tee -a /etc/fstab
echo 'LABEL=aries-data /mnt/data ext4 defaults,noatime 0 2' | sudo tee -a /etc/fstab

sudo systemctl daemon-reload     # systemd regenerates mount units from edited fstab
sudo mount -a
```
`noatime` cuts needless metadata writes — good habit on any node.

**Verify BEFORE installing k3s (critical ordering requirement):**
```bash
findmnt /var/lib/rancher/k3s/server/db     # must show nvme0n1p1
findmnt /mnt/data                          # must show nvme0n1p2
lsblk -f
```
If the etcd partition is **not** mounted here, k3s will write etcd onto the SD card and the mount will later hide it. Do not proceed until `findmnt` confirms the mount.

Troubleshooting:
- `special device LABEL=... does not exist` → label didn't set. Check `sudo blkid`; fix with `sudo e2label /dev/nvme0n1p1 aries-etcd`.
- fstab edited but "systemd still uses the old version" → run `sudo systemctl daemon-reload`, then `sudo mount -a`.
- Test `mount -a` immediately after editing fstab — a bad entry caught now is a typo; caught at next boot it can hang the boot.

---

## 4. Install k3s (first server, quorum-capable, embedded etcd)

```bash
curl -sfL https://get.k3s.io | sh -s - server --cluster-init --secrets-encryption
```

`--cluster-init` initializes **embedded etcd** (not the default SQLite). This is what makes the dedicated etcd partition meaningful and lets you add cp-2/cp-3 later without rebuilding — the single-server-now → HA-later path.

`--secrets-encryption` encrypts Secrets at rest in etcd. It belongs **at install time**; enabling it later is supported but costs a two-restart enable-and-rekey cycle across every server (§8). Without it, every Secret in the cluster is stored in etcd as base64 — encoding, not encryption — and is directly readable from the NVMe or from any etcd snapshot.

`--disable traefik` is optional if you plan to bring your own ingress via GitOps later. For a first node, leave defaults.

---

## 5. Verify

```bash
sudo systemctl status k3s
sudo k3s kubectl get nodes
sudo k3s kubectl get pods -A
```
Healthy target:
```
NAME         STATUS   ROLES                AGE   VERSION
aries-cp-1   Ready    control-plane,etcd   ...   v1.36.2+k3s1
```
- `Ready` isn't instant — the node registers immediately, then flips `NotReady → Ready` (~20–30 s) once flannel (CNI) and coredns are up.
- `ROLES` showing `control-plane,etcd` confirms embedded etcd is running.

**kubectl without sudo** (convenience):
```bash
mkdir -p ~/.kube
sudo cp /etc/rancher/k3s/k3s.yaml ~/.kube/config
sudo chown $(id -u):$(id -g) ~/.kube/config
export KUBECONFIG=~/.kube/config        # add to ~/.bashrc to persist
kubectl get nodes
```

---

## 6. Expanding the cluster later (reference)

Node-join token (needed for cp-2/cp-3 and workers):
```bash
sudo cat /var/lib/rancher/k3s/server/node-token
```
- **Add another server (control-plane quorum):** on cp-2/cp-3, install with `server --server https://<cp-1-ip>:6443 --token <token> --secrets-encryption` (still on their own etcd partitions). The flag goes on every server (§8); a server started without it cannot read what the others wrote.
- **Add a worker (agent):** install with `agent --server https://<cp-1-ip>:6443 --token <token>`.
- HA needs **3 servers** for etcd quorum: 1 = SPOF, 2 = worse than 1, 3 = any single node can be pulled live.

---

## 7. Automate this (do it after the first hand-run)

Everything above is deterministic → it belongs in an Ansible **base role** so cp-2/cp-3/storage are a one-command apply, not a repeat:
- cmdline params (cgroup + NVMe) — universal, every node
- partition + label + fstab (role-conditional: storage gets large data, cp gets minimal)
- k3s install (server `--cluster-init` for first, `server --server` for HA joins, `agent` for workers)
- `--secrets-encryption` on every server (§8) — trivial as an install flag, awkward to retrofit, and therefore role-managed rather than per-node manual
- hostname per inventory
- kubeconfig fetch

Fleet mapping (from the main design doc): `aries-cp-1..3` = Pi 5 2 GB servers; `aries-st-1` = Pi 5 4 GB storage; `aries-gw` = Pi 4 gateway (not in k3s); `aries-face` = Pi 3A+ (LED/kiosk, not in k3s).

---

## 8. Secrets encryption at rest

Kubernetes Secrets are **base64-encoded, not encrypted**. On a k3s server with embedded etcd they live on the etcd partition (§2) in a form anyone with the disk can read. `--secrets-encryption` makes the API server encrypt them (AES-CBC) before they reach etcd, using a key in `/var/lib/rancher/k3s/server/cred/encryption-config.json`.

### Scope of protection

The flag name overstates its reach. What it covers:

- **Offline access to the data** — a stolen NVMe, an etcd snapshot copied elsewhere, a decommissioned disk leaving the premises. This is the case the flag genuinely addresses.

What it does not cover:

- **Callers holding `get secrets` RBAC.** The API server decrypts transparently; `kubectl get secret -o yaml` returns plaintext exactly as before.
- **Root on the server node.** The key resides on the same disk as the data it protects, so a whole-node compromise yields both halves.

The flag therefore hardens backups and retired disks. It is not a substitute for RBAC discipline, nor for keeping secret material out of the cluster in the first place.

### Enabling on an existing cluster

New builds set the flag at install (§4). Retrofitting takes **two restarts**, not one — `enable` only stages the change:

```bash
sudo k3s secrets-encrypt status        # Encryption Status: Disabled, no configuration file found
sudo k3s secrets-encrypt enable        # generates the key, stages the change
```

Add `--secrets-encryption` to the server's own arguments (`/etc/systemd/system/k3s.service` or `/etc/rancher/k3s/config.yaml`) so the flag survives the restart and every restart after it, then restart:

```bash
sudo systemctl restart k3s
sudo k3s secrets-encrypt status        # Encryption Status: Disabled / Current Rotation Stage: start
```

`Disabled` here is expected, not a failure. Nothing is encrypted yet, and existing Secrets are untouched. The rewrite is a second step, followed by a second restart:

```bash
sudo k3s secrets-encrypt rotate-keys   # rotates and reencrypts; ~5 secrets/second
sudo systemctl restart k3s             # same arguments as before
sudo k3s secrets-encrypt status        # Encryption Status: Enabled / Stage: reencrypt_finished
```

Stopping after `enable` is the common failure: the flag is set and the config file exists, so the change looks complete, while status still reads `Disabled` and every pre-existing Secret is still plaintext on disk. Encryption is only real once status reports `Enabled` and `reencrypt_finished`.

### Key rotation

Current k3s performs the prepare → rotate → reencrypt sequence in a single command, and a restart afterwards is part of the sequence:

```bash
sudo k3s secrets-encrypt rotate-keys
sudo systemctl restart k3s
sudo k3s secrets-encrypt status        # Stage: reencrypt_finished, one active key
```

Rotation is warranted on suspected key or node exposure, and after any recovery from a lost or restored disk. Note that this is the same command that completes the retrofit above — an unencrypted cluster is just the case where the old key does not exist yet.

### Key backup

Once Secrets are encrypted, `encryption-config.json` is the **only** means of reading an etcd snapshot. If it is lost, every encrypted Secret becomes unrecoverable and an etcd backup alone is worthless.

Storing the key alongside the etcd snapshots negates the protection, as a single compromised backup set then yields both halves. The key belongs somewhere the snapshots are not — a password manager or an offline copy. Whether a snapshot from the previous month is still decryptable is a reasonable check to include in any restore drill.

### HA considerations (Phase 3+)

With a single server, `enable` and `rotate-keys` are one command on one host. Once cp-2/cp-3 join (§6) the shape changes: pick **one** server to run the `secrets-encrypt` commands from, and after each phase — `enable`, then `rotate-keys` — restart **every** server before starting the next phase. A partial rollout leaves servers disagreeing on how to read etcd.

Restarts should be sequenced one host at a time to preserve etcd quorum. `secrets-encrypt status` reports `Server Encryption Hashes: All hashes match` once the fleet has converged; that line, not the restart finishing, is the signal that the phase is done.

### Related

This section covers Secrets at rest within the cluster. It does not address how secret material reaches the cluster: credentials created by hand via `kubectl create secret` exist only in etcd and are not reproducible from this repository. That is a separate, currently open concern.

---

## Appendix — full cmdline.txt parameter block

Append to the single existing line in `/boot/firmware/cmdline.txt`:
```
cgroup_memory=1 cgroup_enable=memory nvme_core.default_ps_max_latency_us=0 pcie_aspm=off pcie_port_pm=off
```

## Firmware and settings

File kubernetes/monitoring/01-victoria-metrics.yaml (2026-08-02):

# VictoriaMetrics (single-node) — the time-series database.
#
# Chosen over Prometheus per design-doc.md §5, which caps monitoring at
# "metrics-server + Netdata; VictoriaMetrics later if historical graphs are
# wanted; full Prometheus only if an 8GB node appears". VM is a single Go
# binary that holds the same PromQL surface in roughly a fifth of the memory,
# which is what makes historical graphs affordable on a 2GB control-plane node
# that is also running etcd.
#
# It scrapes directly (no separate vmagent) — one less pod on a small fleet.

apiVersion: v1
kind: ServiceAccount
metadata:
  name: victoria-metrics
  namespace: monitoring
---
# Service discovery needs read access to the API, and scraping the kubelet
# goes through the API server's node proxy (nodes/proxy).
apiVersion: rbac.authorization.k8s.io/v1
kind: ClusterRole
metadata:
  name: victoria-metrics
rules:
  - apiGroups: [""]
    resources: [nodes, nodes/proxy, nodes/metrics, services, endpoints, pods]
    verbs: [get, list, watch]
  - nonResourceURLs: ["/metrics", "/metrics/cadvisor"]
    verbs: [get]
---
apiVersion: rbac.authorization.k8s.io/v1
kind: ClusterRoleBinding
metadata:
  name: victoria-metrics
roleRef:
  apiGroup: rbac.authorization.k8s.io
  kind: ClusterRole
  name: victoria-metrics
subjects:
  - kind: ServiceAccount
    name: victoria-metrics
    namespace: monitoring
---
apiVersion: v1
kind: ConfigMap
metadata:
  name: victoria-metrics-scrape
  namespace: monitoring
data:
  scrape.yml: |
    global:
      scrape_interval: 30s        # 30s rather than 15s halves both CPU cost and
                                  # disk growth, at resolution adequate here.

    scrape_configs:
      # ---- kubelet's own metrics (per-node, via the API server proxy) ----
      - job_name: kubernetes-nodes
        scheme: https
        tls_config:
          ca_file: /var/run/secrets/kubernetes.io/serviceaccount/ca.crt
          insecure_skip_verify: true
        bearer_token_file: /var/run/secrets/kubernetes.io/serviceaccount/token
        kubernetes_sd_configs:
          - role: node
        relabel_configs:
          - action: labelmap
            regex: __meta_kubernetes_node_label_(.+)
          - target_label: __address__
            replacement: kubernetes.default.svc:443
          - source_labels: [__meta_kubernetes_node_name]
            regex: (.+)
            target_label: __metrics_path__
            replacement: /api/v1/nodes/$1/proxy/metrics

      # ---- cAdvisor: per-container CPU/memory, i.e. which pod is consuming
      #      a given node's limited RAM ----
      - job_name: kubernetes-cadvisor
        scheme: https
        tls_config:
          ca_file: /var/run/secrets/kubernetes.io/serviceaccount/ca.crt
          insecure_skip_verify: true
        bearer_token_file: /var/run/secrets/kubernetes.io/serviceaccount/token
        kubernetes_sd_configs:
          - role: node
        relabel_configs:
          - action: labelmap
            regex: __meta_kubernetes_node_label_(.+)
          - target_label: __address__
            replacement: kubernetes.default.svc:443
          - source_labels: [__meta_kubernetes_node_name]
            regex: (.+)
            target_label: __metrics_path__
            replacement: /api/v1/nodes/$1/proxy/metrics/cadvisor
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

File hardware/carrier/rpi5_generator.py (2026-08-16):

"""A Raspberry Pi 5 built from its mechanical drawing.

This is the board the rack builds and sizes itself against, in place of the
featureless 85x56 slab in `pcb_generator.py`: every outline the drawing draws,
at the coordinates it draws them, extruded to the heights its side view
dimensions. Modelling the real thing is what makes bay clearances answerable --
a slab has no microSD socket under it, nothing overhanging its edges, and no
15.8mm USB stack reaching into the bay above.

It doubles as the parameter source for the rest of the model, which is why its
properties carry the shared names (`Width`, `Length`, `Thickness`,
`HoleDiameter`, and the four hole offsets) and its object is called
`Parametric_PCB`.

Geometry was recovered from the vector content of Raspberry Pi Ltd drawing
RP-008347-DS-1 (`.claude/RP-008347-DS-1-raspberry-pi-5-mechanical-drawing.pdf`)
rather than read off the printed callouts, so the footprints carry the
drawing's own precision. Board coordinates put x 0..85 across the drawing's
plan view and y 0..56 up it, which places the GPIO header along y=56 and the
Ethernet and USB stacks against x=85. The PCB occupies z 0..Thickness and every
component height is measured from its top face, matching the side view.

Parts are grouped into one object per material -- green laminate, nickel port
shells, gold pins, black plastic and packages, and so on -- so the board is
recognisable in the 3D view. That is presentation, not drawing data: the
drawing is line art in two colours and says nothing about materials. Colour is
a view property, so a document built headless by `freecadcmd` has none until
it is opened in the GUI; `apply_colours()` puts them on.

The drawing's own caveat applies to this model too: dimensions are approximate
and for reference, and not all board components are shown.

Run standalone:  freecadcmd hardware/carrier/rpi5_generator.py
"""

import os
import sys

import FreeCAD as App
import Part

# FreeCAD puts only the running script's own directory on sys.path, so a
# generator started directly from `carrier/` cannot see hardware_utils one
# level up. Add the hardware root before importing it.
_HARDWARE_ROOT = os.path.dirname(os.path.dirname(os.path.abspath(__file__)))
if _HARDWARE_ROOT not in sys.path:
    sys.path.insert(0, _HARDWARE_ROOT)

import hardware_utils

# Height to give a footprint the drawing plans but never elevates. The side
# view is taken from the y=0 edge, so the GPIO header screens most of the
# board's silicon and the drawing simply omits it; only components that clear
# the header, or stand outside its 7.1..57.9 span, are dimensioned. 1.2mm is
# the smallest height the side view does show, and it is a placeholder -- these
# blocks are the drawing's footprints at an invented thickness, not measurements.
UNDIMENSIONED_HEIGHT = 1.2

# What each part is made of. Nothing in the drawing says -- it is line art in
# two colours -- so these are read off a real board, and they exist to make the
# model recognisable in the 3D view rather than to assert anything. Parts are
# grouped into one object per material, because a FreeCAD solid carries a
# single colour and grouping is the robust way to get several: per-face
# DiffuseColor would have to be reapplied every time a boolean renumbers faces.
#
#   key:        (object name,       colour)
MATERIALS = {
    "Shell":    ("Port_Shells",     (0.80, 0.82, 0.85)),  # nickel-plated steel
    "Contact":  ("Header_Pins",     (0.83, 0.69, 0.31)),  # gold-plated pins
    "Plastic":  ("Black_Plastic",   (0.08, 0.08, 0.09)),  # connector bodies
    "Package":  ("Packages",        (0.13, 0.13, 0.14)),  # black epoxy
    "Passive":  ("Passives",        (0.62, 0.60, 0.56)),  # ceramic and tantalum
    "Button":   ("Power_Button",    (0.72, 0.11, 0.13)),  # the Pi 5's red cap
}
LAMINATE_COLOUR = (0.09, 0.40, 0.18)  # solder mask

# The three tables below are all (label, x0, y0, x1, y1, ..., material) in board
# coordinates, with heights measured from the PCB's top face. Each material is
# fused into one solid, so the labels are here to name what a row came from
# rather than to become object names.

# The connectors. Every one of these is dimensioned: the plan view fixes the
# footprint and the side view fixes the height.
CONNECTORS = [
    # Along the y=0 edge, overhanging it. The drawing's 11.2 / 25.8 / 39.2
    # callouts are the x centres of these three, and they come out at 11.195,
    # 25.795 and 39.200.
    ("USB_C",         6.82, -1.32, 15.57,  5.99,  3.2, "Shell"),
    ("Micro_HDMI_0", 22.20, -1.67, 29.39,  6.87,  3.4, "Shell"),
    ("Micro_HDMI_1", 35.60, -1.67, 42.80,  6.87,  3.4, "Shell"),
    # The two 22-way MIPI camera/display flexes, standing off the same edge.
    ("MIPI_FPC_0",   47.25,  0.69, 50.21, 16.18,  4.1, "Plastic"),
    ("MIPI_FPC_1",   53.45,  0.69, 56.38, 16.18,  4.1, "Plastic"),
    # The PCIe flex, on the opposite edge.
    ("PCIe_FFC",      1.24, 24.75,  4.21, 35.27,  4.1, "Plastic"),
    # The port block, overhanging x=85 by the side view's 3mm -- drawn as 2.99
    # for the RJ45 and 2.89 for the two USB shells, which the callout rounds.
    # Their y centres are the 10.2 / 29.1 / 47 callouts: 10.200, 29.060, 46.995.
    ("Ethernet",     66.75,  2.21, 87.99, 18.19, 13.9, "Shell"),
    ("USB_A_Stack_0", 70.95, 21.76, 87.89, 36.36, 15.8, "Shell"),
    ("USB_A_Stack_1", 70.95, 39.71, 87.89, 54.28, 15.8, "Shell"),
]

# Through-hole headers, modelled as a plastic body carrying square pins -- so
# each one splits between the Plastic and Contact materials. Both bodies are
# the 2.5mm the side view shows between pins.
HEADER_BODY_HEIGHT = 2.5
HEADER_PIN_SIZE = 0.64
HEADER_PITCH = 2.54

# (label, x0, y0, x1, y1, pin height, first pin centre, columns, rows)
HEADERS = [
    ("GPIO_Header", 7.10, 50.01, 57.90, 54.99, 8.6, (8.37, 51.23), 20, 2),
    ("PoE_Header", 58.99,  7.01, 64.00, 11.98, 8.5, (60.23,  8.23),  2, 2),
]
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

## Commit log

2026-07-12 Initial commit: Aries 28 design docs, hardware specs, and cluster manifests
    A tower-format Raspberry Pi mini private data center: a k3s learning
    platform and documented open-hardware build.
    - docs/: architecture, design doc, network, DNS/exposure, rack, lighting,
    node-setup runbook, plus diagrams and concept renders
    - hardware/: fabrication files and per-part READMEs (carrier, rack, frame,
    panels, power bay, switch mount, cable brace, connection panel)
    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
    [carrier-holder.stl, rack.stl]
2026-07-12 docs: adopt hybrid addressing (static gw, reserved CP, dynamic rest)
    Replace the static-vs-reservations muddle with one hybrid scheme now that
    DHCP is in place:
    - gateway static at .1 (it serves DHCP/DNS, cannot lease itself)
    - control-plane servers reserved (.11-.13) — etcd peer URLs + API TLS SAN
    bind to node IP, so servers need stable addresses
    - storage, workers, face, and transient devices fully dynamic, named via
    dnsmasq *.aries.lan (agents join through the servers' stable addresses)
    Aligned across network-design §1/§4, dns-and-exposure §9, design-doc §2.1,
    and ansible/README.
2026-07-12 docs: rename sled->carrier and settle two-pitch rack (30mm / 42mm)
    Two related physical-design reconciliations:
    - Terminology: design-doc §3 used the old "sled"/"printed rails" vocab
    while every other doc uses "carrier" + the rod-and-bead rack. Renamed
    throughout and pointed at rack-design.md / hardware/carrier/.
    - Pitch: resolve the single-35mm-plus-70mm-double model (design-doc,
    rack-design) vs the two-pitch model (architecture) in favour of two
    pitches: 30mm compute / 42mm extended. Storage now lives in a 42mm
    extended bay rather than a doubled bay. Aligned design-doc §3.1,
    architecture §6, rack-design (R3 + bead system + open questions),
    and the rack/carrier/hardware p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
2026-07-12 docs: fix fan spec to single 140mm ARCTIC P14 in power table + BOM
    design-doc §3.3.1 and lighting-design specify one 140mm ARCTIC P14 Pro
    A-RGB, but the power budget table §4.1 and BOM §7 still listed "2x 120mm
    fans". Align both to the single 140mm fan (~3W); theoretical-max row
    adjusted 197 -> 196W accordingly.
2026-07-12 docs: drop 74AHCT125 for Arduino Nano LED driver; de-personalize Nano
    lighting-design §3.2 settled the Tier-2 LED driver on an Arduino Nano
    (5V-native, eliminates the 74AHCT125 level shifter); design-doc §3.4 and
    the BOM still listed the shifter. Align §3.4 to the USB-serial -> Nano ->
    WS2812 path.
    Also remove builder-specific "owned/free" framing for the Nano (irrelevant
    to replicators): it's now a buyable ~$4 part in both the main BOM and the
    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
2026-07-12 docs: remove builder-specific "owned" framing
    Ownership of parts is irrelevant to anyone replicating the build. Drop the
    fleet §2.2 Source column, the "owned" acrylic/panel phrasing, the "owned
    board" bench step, and the COB-strip "owned" in the lighting BOM (now a
    buyable ~$8 line). Kept the two legitimate uses: the BOM's "assuming
    nothing owned" costing basis and "publicly owned domain" in the DNS doc.
2026-07-12 docs: align fleet-table storage to 256GB NVMe
    Fleet table §2.2 listed st-1 as "512GB-1TB" while §4.3 and the BOM specify
    the deliberately right-sized 256GB Vansuny (1TB-class upgrade deferred).
    Match the table to the reasoned current choice.
2026-07-12 docs: fix stale repo layout in design-doc §6
    §6 described directories that don't exist (docs/bom.md, docs/power.md,
    build-log/, hardware/cad|stl|svg/, led-daemon/) and organized hardware by
    format. Replace with the actual tree: hardware organized by part, the real
    docs set, BOM/power folded into this doc, and a note on not-yet-committed
    artifacts. Now consistent with README and hardware/README.
2026-07-12 docs: clarify power table §4.1 is a 10-bay endgame ceiling, not the fleet
    The budget table's "7x Pi 5 / 2x storage" counts read as if they were the
    current fleet (which is 4 Pi 5s + 1 storage). Reframe the caption as an
    explicit hypothetical fully-populated endgame used to size the 200W PSU,
    and point the "current fleet peaks ~100W" line at §2.2.
2026-07-12 docs: reconcile node-count framing in design-doc mission
    §1 said "7-node (expandable to 10)", reading as a hard cluster cap and
    clashing with the README's "single node -> no fixed limit" framing. Recast
    10 as the single-box bay capacity (seven populated today) within an
    unbounded, multi-box growth model, pointing at network-design §6.
2026-07-25 docs: clarify cp-1's interim NVMe/storage role and cp-2/3's future NVMe
    node-setup.md's NVMe/etcd assumption was correct all along — the fleet
    table just didn't capture the real hardware story: cp-1 currently
    carries the fleet's only NVMe (etcd partition + an interim data
    partition standing in for the not-yet-built st-1), and cp-2/cp-3 will
    each need their own NVMe for etcd when they join for Phase 3+ HA,
    since SD isn't recommended for etcd's fsync-heavy writes.
    Update the §2.2 fleet table, §2.3 control-plane strategy, and §4.3
    storage-hardware section to describe this current-vs-planned split,
    and bump the BOM's X1001+NVMe line from qty 1 to 4 accordingly
    (~$970 component sum, ~$1,150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
2026-07-25 docs: update rack bay-pitch wording for NVMe on every cp node
    Now that every control-plane node carries an X1001 NVMe HAT for etcd
    (not just the storage node), the extended 42mm pitch covers most of
    the compute fleet rather than a single node, and the dense 30mm pitch
    is left with only the bare/diskless nodes (gateway, light worker,
    face). Update architecture.md §6, design-doc.md §3.1, and
    rack-design.md's R3 requirement and extended-bead note accordingly —
    wording only, no bay-count/geometry redesign (still pending CAD work
    per rack-design.md §10).
    Claude-Session: https://claude.ai/code/session_01TKZ6pS2JWGXgZYXifMJNLc
2026-07-25 docs: move switch from top "network shelf" to facilities deck
    design-doc.md §3.1 put the switch on a top "Network shelf," but
    architecture.md §5, network-design.md §5.1, and the switch-mount
    hardware README all place switching on the bottom facilities deck
    alongside the PSU and fuse block. Collapse the stale three-zone list
    into the two-deck model used everywhere else in the docs.
    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
2026-07-25 docs: give the gateway a second NIC in the BOM for its WAN uplink
    dns-and-exposure.md already described the gateway as having "two
    network interfaces" (home-LAN + Aries-internal), but a Pi 4 has only
    one onboard Ethernet port, and the BOM's sole USB3-GbE adapter was
    already spoken for by the face node. Add a second USB3-GbE adapter to
    the BOM for the gateway's WAN uplink, with the onboard port serving
    the internal switch trunk (network-design.md §5.2's existing
    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
2026-07-25 docs: split LED circuit from face-node circuit, fix fuse undersizing
    §4.2 shared a 5A fuse between the face node, the 7" display, and the
    LED strips. §9.2 already stated the brightness cap holds worst-case
    LED draw to ~30W, which is 6A at 5V — before even adding the face
    node (~1A) and display (~0.8A). The capped worst case alone exceeded
    the shared fuse's rating.
    Split the LEDs onto their own 10A circuit, sized to the §4.1 endgame
    pixel budget rather than today's partial build, and leave the face
    node + display on their own 5A circuit (well within margin at ~1.8A).
    This also means an LED-side fault can no longer take the face node
    down with it, which matters since the face node drives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
2026-07-25 docs: fix three-switch cascade port arithmetic (22 -> 20 usable)
    network-design.md §5.1 claimed 3x 8-port switches cascaded give
    "≈22 usable ports," but a cascade link consumes a port on both ends,
    not one: chaining three switches is two links, four ports lost, so
    24 - 4 = 20, not 22. design-doc.md's own two-switch math (16 ports,
    one link, 14 usable) already had this right — cross-reference it.
    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
2026-07-25 docs: fix carrier naming scheme in hardware README to match design doc
    hardware/carrier/README.md named per-generation variants
    (carrier-rpi5.*, carrier-rpi4.*) as if the Pi 4 and Pi 5 needed
    different mounting holes. design-doc.md §3.2 already establishes a
    shared carrier-rpi-b.* for the whole Pi 3B/4B/5 family, since they
    share one 85x56mm footprint and hole pattern. Align the hardware
    README with that scheme.
    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
2026-07-25 docs: add the missing grounding/GFCI content §4 was supposed to have
    README.md claims mains safety (grounding, GFCI) "is addressed in the
    design doc," and §3.3 references "the frame-bond ground lead (§4),"
    but §4 had no grounding, GFCI, or frame-bonding content at all — a
    real gap for a design that puts mains wiring on display behind a
    smoked panel. Add a grounding & GFCI bullet to §4.2 covering the
    frame-bond star point, AC-earth/DC-negative separation, and a
    GFCI/RCD recommendation for the AC circuit, and tighten the §3.3
    cross-reference from §4 to §4.2.
    Claude-Session: https://claude.ai/code/session_01TKZ6pS2JWGXgZYXifMJNL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
2026-07-25 docs: add missing XL6019 boost converter to BOM
    design-doc.md §3.3.1 and lighting-design.md §3.3 both require an
    XL6019 5V->12V boost converter for the fan motor, but no BOM line
    covered it. Add it and recompute the totals in design-doc.md §1/§7
    and README.md (+$4).
    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
2026-07-25 docs: unify soft-power control and console-port terminology
    Three docs described what turned out to be the same soft-power
    control inconsistently: design-doc.md §4.4 called it a "front-panel"
    DPST toggle while also placing its footprint in the power bay;
    network-design.md §8.1 and the connection-panel hardware README
    called it a rear-panel "power button," which reads as momentary even
    though the circuit topology (§4.4 Pole 1 carries AC load continuously)
    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
2026-07-25 docs: drop stray lithium-battery mention from LICENSE safety notice
    The design has no batteries anywhere (§4.4's soft-power circuit is
    explicitly "no battery"), so the lithium-wiring warning was
    inapplicable boilerplate. Trim it to the DC wiring that's actually
    in the build.
    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
2026-07-25 docs: add missing [BUY] tag to rack in hardware parts index
    hardware/README.md's parts index listed the rack as [PRINT] only, but
    hardware/rack/README.md correctly notes the stainless rods are bought
    (printed beads/plates + bought rods). Add the [BUY] tag for
    consistency between the two.
    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
2026-07-25 hardware: replace carrier STL/SVG with laser-fab carrier-rpi-b.svg
    Remove the old carrier-holder.stl and carrier-holder-source.svg and
    add carrier-rpi-b.svg, a laser-fabrication file built to work with
    the new rod-and-bead rack top/bottom plates. It nests the
    vertical-isolation spacers as cutouts within the same file, cut from
    the plate's own waste material in one laser pass, rather than
    requiring a separately-designed spacer part.
    Update the carrier, spacer, and hardware parts-index READMEs to match:
    the sheet route now ships with nested spacers, the printed route's
    STL (with spacers built directly into the print) is still pending,
    and the standalone spacer design is noted as superseded fo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
    [carrier-holder.stl]
2026-07-25 hardware: replace rack.stl with laser-fab rack-top-bottom.svg
    Same swap as the carrier commit, for the rack: remove the old printed
    rack.stl and add rack-top-bottom.svg, laser-cut top/bottom plates for
    the rod-and-bead cartridge with rod holes matching
    carrier/carrier-rpi-b.svg's rod/pivot bores. These two files share a
    critical interface (rod spacing) and are designed together, not
    independently — flagged explicitly in both READMEs so a future change
    to one doesn't drift from the other.
    Update hardware/rack/README.md's fabrication-route breakdown (plates
    now SHEET, beads still PRINT, rods still BUY), the hardware parts
    index, and rack-design.md's rod-ends note to match.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
    [rack.stl]
2026-07-25 hardware: strip Shaper metadata, fix glyph visibility + laser layering
    Both SVGs carried Shaper Origin-specific metadata (xmlns:shaper
    namespace, shaper:cutType/cutOffset/toolDia on every path) left over
    from the authoring tool. Remove it from both files, consistent with
    the project's fabrication-by-requirement-not-by-tool approach.
    In carrier-rpi-b.svg, the Aries glyph path had an effective stroke
    width of ~0.005mm (its own 0.0529 transform scale wasn't compensated
    in stroke-width="0.1"), making it invisible in normal SVG viewers.
    Fix by giving it a distinct blue stroke (previously the same gray as
    every cut line) and a stroke-width that lands at a visible ~0.3mm
    after the transform, kept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
2026-08-02 kubernetes: add VictoriaMetrics + Grafana monitoring stack
    Historical metrics and dashboards sized for single-board computers,
    following design-doc.md §5's cap on the monitoring layer: VictoriaMetrics
    rather than Prometheus, which wants 0.5-1.5GB at default settings on a 2GB
    control-plane node that is also running etcd.
    - VictoriaMetrics single-node as the time-series database, scraping
    directly with no separate vmagent. Pinned to the NVMe node through a
    local PersistentVolume bound by node label rather than hostname, so it
    stays correct as more nodes get drives. This keeps a continuous
    small-write workload off the SD card, the same reasoning node-setup.md
    §2 applies to etcd.
    -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
    [01-victoria-metrics.yaml]
2026-08-02 hardware: fix generator entry points and share the rod math
    The generators only ever ran as part of generate_rack.py. freecadcmd imports
    a script as a module rather than executing it as __main__, so every
    `if __name__ == "__main__"` block was dead code, and the per-file scripts
    could not import hardware_utils from the parent directory in any case. Add
    is_main_script() plus a sys.path bootstrap so each generator runs on its own,
    and say so plainly when a plate has no parameter source instead of silently
    producing nothing.
    hardware_utils was also missing from generate_rack.py's reload list, so edits
    to the one module every plate depends on had no effect in a live GUI session.
    Move the shared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
    [pcb_generator.py]
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2026-08-02 hardware: match the Pi hole spec, refresh the cut files, add the bead mesh
    The mounting holes were on a 51mm span. The Pi 3B/4B/5 footprint the carrier
    is built around puts them 58mm apart on 2.7mm holes, as carrier/README.md has
    said all along, so the carrier's standoffs were 7mm out and no board would
    have sat on them.
    Strip the Shaper Origin metadata from the carrier again -- a namespace and
    cutType/cutOffset/toolDia on every path -- the same way it was stripped before
    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
    [rack-bead-30.stl]
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2026-08-02 docs: describe the generated rack, and correct what it superseded
    The rack is no longer drawn, it is generated, and the cut files are exports.
    MODEL.md covers running the generators, what each one builds, the master and
    clone split that keeps the carrier and the beads from depending on each other,
    and the gaps that are known and still open. It also records that a saved
    .FCStd is not parametric on its own: FreeCAD 1.1 blocks the proxy modules on
    restore unless hardware/ is exposed as a Mod directory, and without that the
    file opens looking correct and quietly ignores every parameter.
    Four claims in rack-design.md had been overtaken by the model rather than
    merely aged:
    The swing arc names t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
2026-08-03 kubernetes: raise Grafana's memory limit to 512Mi -> 1Gi
    After a power blip rebooted all three workers, the pod came back on a
    newer grafana:latest that auto-updated three bundled plugins, and settled
    at ~495Mi RSS against the 512Mi ceiling -- 99%, with only ~6Mi of that
    reclaimable page cache.
    It never OOMKilled. Instead it sat at the cliff edge and flapped:
    allocation stalls plus CPU throttling made /api/health miss the readiness
    probe's default 1s timeout, six failures in a row dropped the endpoint
    from the Service, and the ingress started answering 503.
    1Gi restores headroom; w2 carries this comfortably at 39% of 4GB.
    Note that memory expands to fill the new limit (813Mi RSS, 887Mi wo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
2026-08-08 hardware: model the actual Pi 5, from its mechanical drawing
    The rack has only ever known the board as an 85x56 slab, which is all it
    needs to size rods and plates against but not enough to answer a clearance
    question -- where the port block lands, how far the microSD card stands out
    of the edge, how much air a bay needs over the USB stacks.
    So build the board properly, from Raspberry Pi Ltd drawing RP-008347-DS-1:
    outline and corner radii, all six holes, every connector and header, and the
    package footprints the plan view outlines. Nothing reads it -- pcb_generator
    stays the parameter source and the two agree on the outline and the 58x49
    pattern -- so this is a reference model that costs t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
    [rpi5_generator.py]
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2026-08-09 hardware: let the carrier animation rest at each end of its travel
    The GIF ran the whole cycle at one speed, so the two poses worth looking at --
    swung open, and fully withdrawn -- went by in a twentieth of a second each, and
    the loop restarted the instant the carrier was home. Give it four pauses: a
    short one on the rack at rest, a short one swung open, a longer one fully out,
    and a long one back home so the loop reads as a loop rather than a stutter.
    Every frame of a GIF assembled from an image sequence is on screen for the same
    1/FRAME_RATE, so a pause is a number of repeated frames rather than a duration.
    hold() writes those by copying the last frame's file: the pixels are identical
    eit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
2026-08-09 hardware: render the animation oversize so its edges stop crawling
    The GIF looked bad and the encoder was not why. A source frame held about 640
    distinct colours: saveImage renders the view with no anti-aliasing, so every
    sloped edge came out a staircase, and the GIF was a faithful copy of a bad
    picture. Quantising to 256 colours was doing almost no damage on top.
    So render each frame SUPERSAMPLE times oversize and let ffmpeg lanczos it back
    down -- the averaging on the way down is the anti-aliasing. At 3x the same
    frame carries about 11,400 colours before quantisation and the staircase is
    gone. The palette is now built from the scaled-down pixels rather than the
    oversize ones, since a pale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
2026-08-09 docs: set --secrets-encryption at install, document the retrofit
    Kubernetes Secrets are base64, not encrypted, so on the embedded-etcd
    build they sit readable on the etcd partition and in every snapshot.
    Set the flag at install time in the first-server command, and on the
    cp-2/cp-3 join — it has to be on every server or a joining one cannot
    read what the others wrote.
    Add §8 for the parts that are easy to get wrong: what the flag actually
    protects (offline disks and snapshots, not RBAC callers and not root on
    the node), and the retrofit, which takes two restarts rather than one.
    `enable` only stages the change; status still reads Disabled at stage
    `start`, and existing Secrets stay plain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
2026-08-09 hardware: split the bead into a bay base and four bay posts
    A bay was one four-tube bead. It is now a bridged Bay_Base -- the bottom 6mm,
    three webs plus a landing pad at each station -- and four identical Bay_Posts
    standing on those pads. The carrier rides in the pad band, resting on the webs
    and trapped from above by the posts' feet, and still swings out of it.
    Three things fall out of the split that were not the point of doing it:
    The base no longer changes with the pitch. Only the post's length does, so a
    42mm rack reprints one part rather than two, and the 24mm post height is the
    single number a pitch change moves.
    The board gets its clearance back. A post wraps 225 degrees and turns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
    [rack-bay-base.stl, rack-bay-post-30.stl, rack-bead-30.stl]
2026-08-15 hardware: give the bay base a cable comb on its rear bridge
    The ethernet comes up the rack from below, so the back of the rear bridge now
    carries a row of eight C-clips: press a cable in through the mouth and it stays
    there. Eight because the bottom bay's comb has to pass every bay's cable on the
    way up, so the row is as long as the rack is deep in bays.
    Sizes are imperial because the cable is. A Cat5e/6 jacket is a whisker under
    7/32", and the mouth at 5/32" is narrow enough that a cable has to be pressed
    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
    [rack-bay-base.stl]
2026-08-16 hardware: run the power leads too, and clip the drop off the RR post
    Two additions, both about getting cable off the base and up the rack.
    A power comb on the left web, opposite number to the ethernet comb on the
    rear bridge. The XT30 pigtail's red and black leads are 3/32in each and
    bonded, so a clip here is not a bore but a stadium two wire diameters long
    and one wide standing normal to the web: the pair drops in on edge, red
    inboard against the web and black outboard behind it. Nothing pinches
    between the two -- a bonded pair cannot be threaded in a lead at a time, so
    a waist would only be something to fight. Mouth at 90% of the wire, which
    is looser than the ethernet comb's 71% and can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
    [rack-bay-base.stl, rack-bay-post-rr-30.stl]

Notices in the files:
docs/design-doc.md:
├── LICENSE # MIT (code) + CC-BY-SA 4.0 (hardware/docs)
